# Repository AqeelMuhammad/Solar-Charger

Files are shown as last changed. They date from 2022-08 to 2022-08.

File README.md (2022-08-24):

# SOLAR BANK - Portable Solar Charger

<!-- PROJECT LOGO -->
<br />
<div align="center">
  <a href="https://github.com/AqeelMuhammad/Solar-Charger">
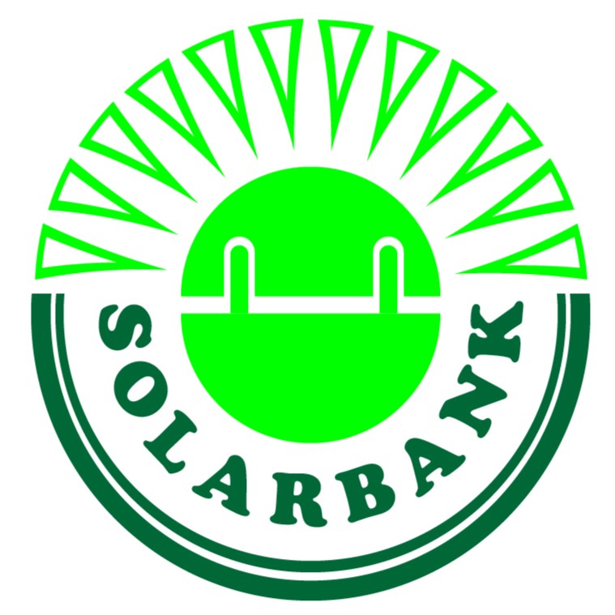
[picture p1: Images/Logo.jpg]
    
  </a>
  <h3 align="center">SOLAR BANK</h3>
</div>

# About The Project

<div align="center">
  <a href="https://github.com/AqeelMuhammad/Solar-Charger">
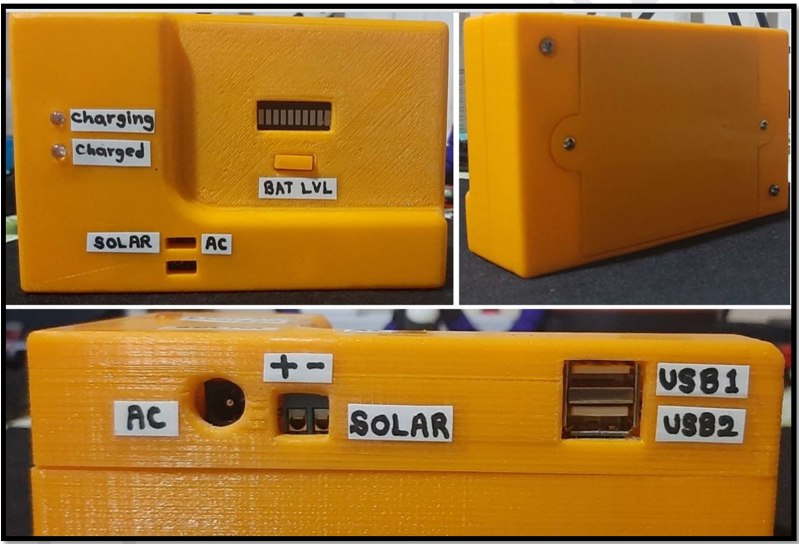
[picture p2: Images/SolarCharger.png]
    
  </a>
</div>

* This repository includes all the project files related to the development of a portable solar charger; Solar Bank. 
* The project was done by a team of 10 undergraduates at the Department of Electronic and Telecommunication Engineering, University of Moratuwa, Sri Lanka for UOM's EN3023 - Electronic Design Realization module.
* We Designed a portable mobile charger capable of powering small electronic devices which can be charged by solar cells or AC power. This device can be carried while hiking, traveling or can be installed in public places even at home.
* `Altium Designer` and `SolidWorks` were used to design the circuit designs and the enclosure designs.

# Printed Circuit Board (PCB)

|*3D Layout*|*Before Soldering*|*After Soldering*|
|:----:|:----:|:----:|
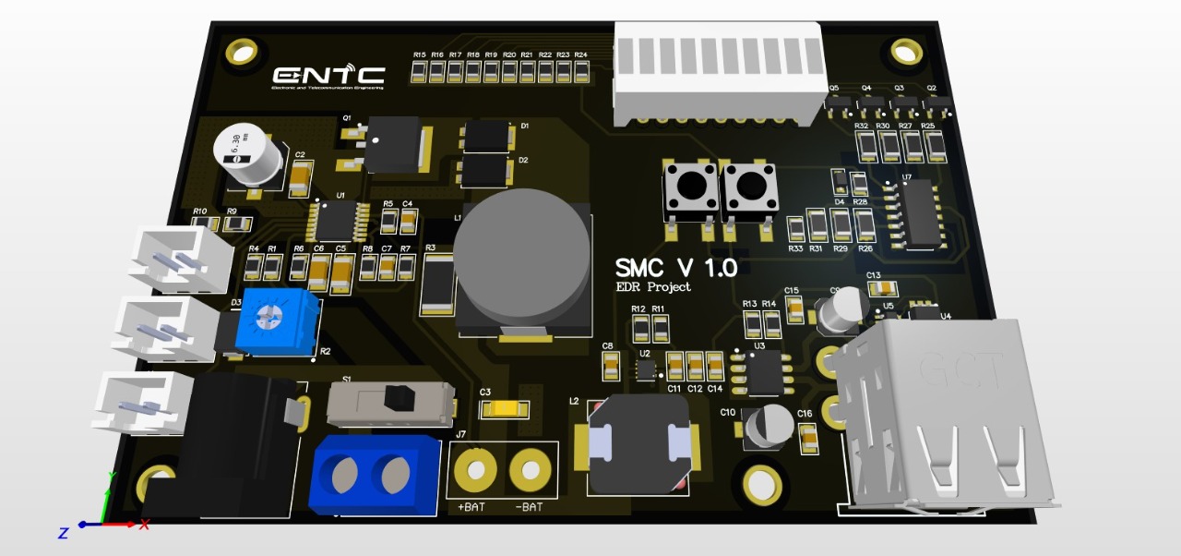
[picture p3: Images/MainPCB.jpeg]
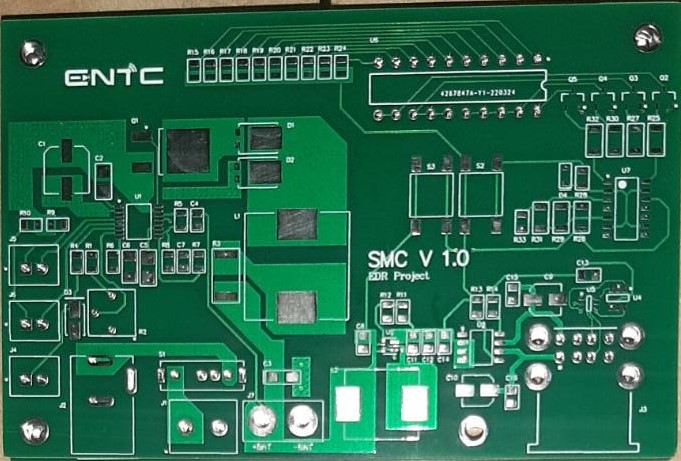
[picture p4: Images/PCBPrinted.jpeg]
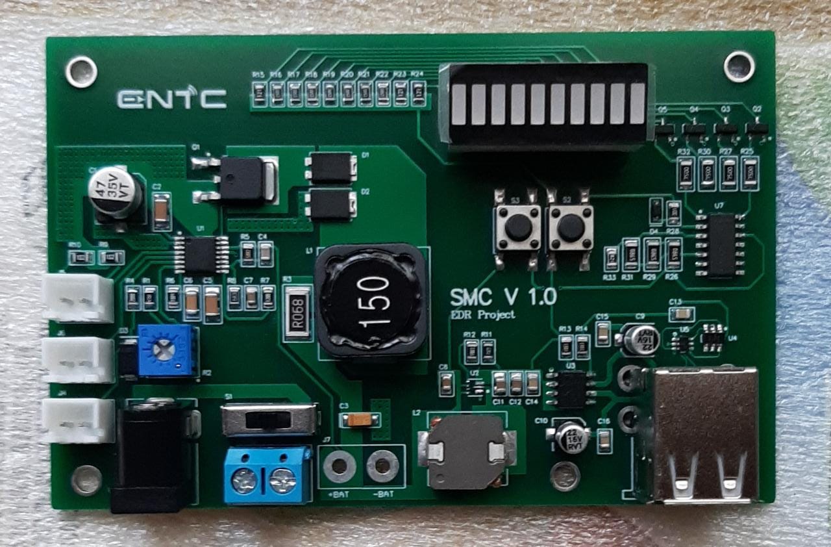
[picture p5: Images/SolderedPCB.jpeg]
|  |||

# Enclosure

|*SolidWork Design*|*Before Printing*|*After Printing*|
|:----:|:----:|:----:|
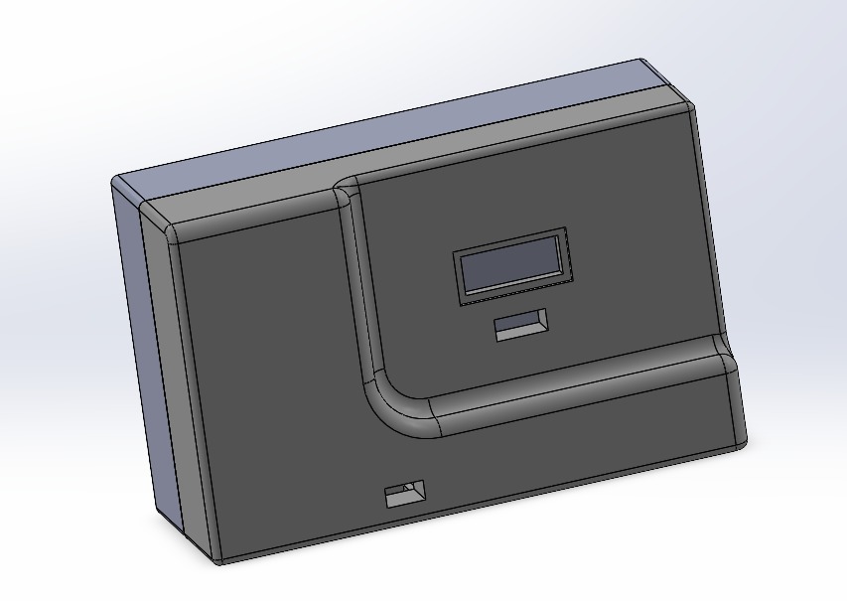
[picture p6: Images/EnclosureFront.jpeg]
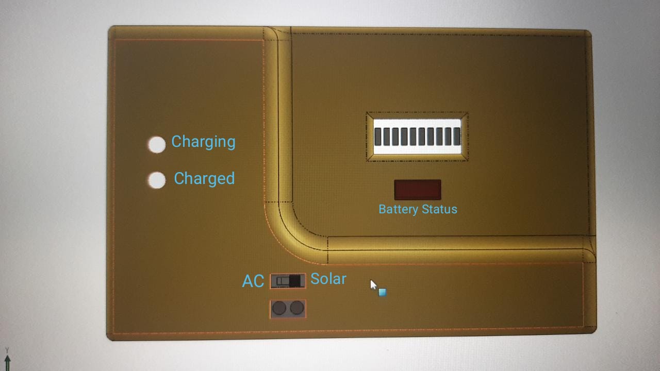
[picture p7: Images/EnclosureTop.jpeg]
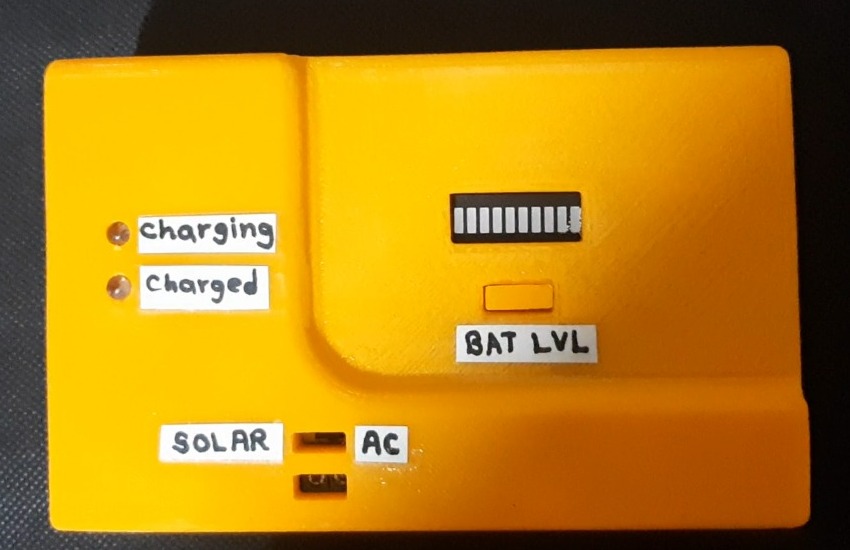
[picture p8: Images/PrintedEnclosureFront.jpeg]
|  |||

### Contributors

1. [Muhammad Aqeel](https://github.com/AqeelMuhammad)
1. [Charith Janaka](https://github.com/charithjanaka)
1. [Tharuka Nilupul](https://github.com/TharukaN17)
1. [Isuru Dilshan Wijethunga](https://github.com/IsuruWijethunga)
1. [Dilun Sandeepa](https://github.com/Diluwas)
1. [Navindu Rasanjana](https://github.com/NavinduRasanjana)
1. [Dulsara Gimhana](https://github.com/Dulsara20059)
1. [Aruna Lakpriya](https://github.com/aruna-lakpriya)
1. [Kaveesha Yalegama](https://github.com/Kaveesha-98)
1. [Janitha Vidunath](https://github.com/JanithaVidunath)

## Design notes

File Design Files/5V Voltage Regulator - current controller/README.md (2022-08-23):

# Step Down Voltage Regulator

* A voltage regulator and voltage step down circuit for the charger.

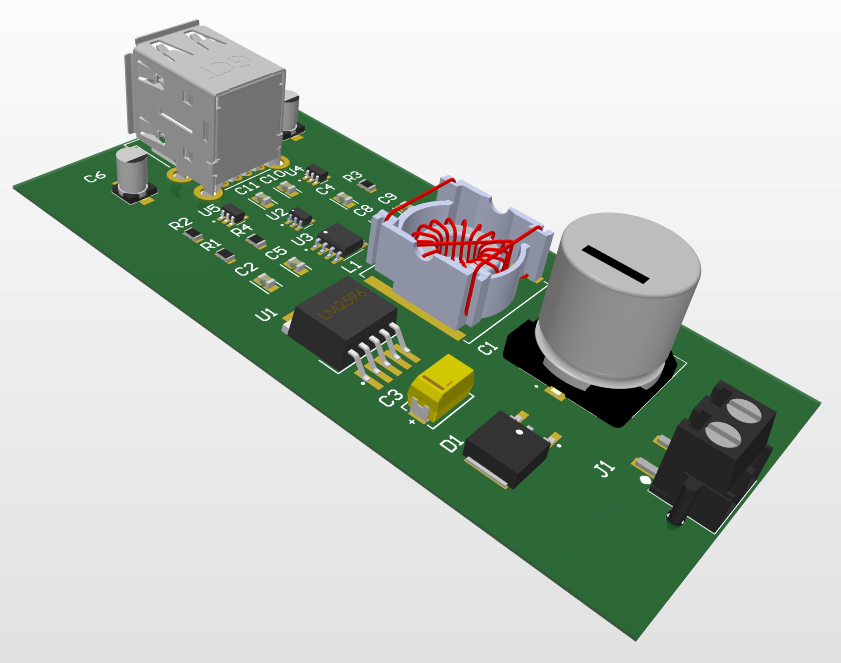
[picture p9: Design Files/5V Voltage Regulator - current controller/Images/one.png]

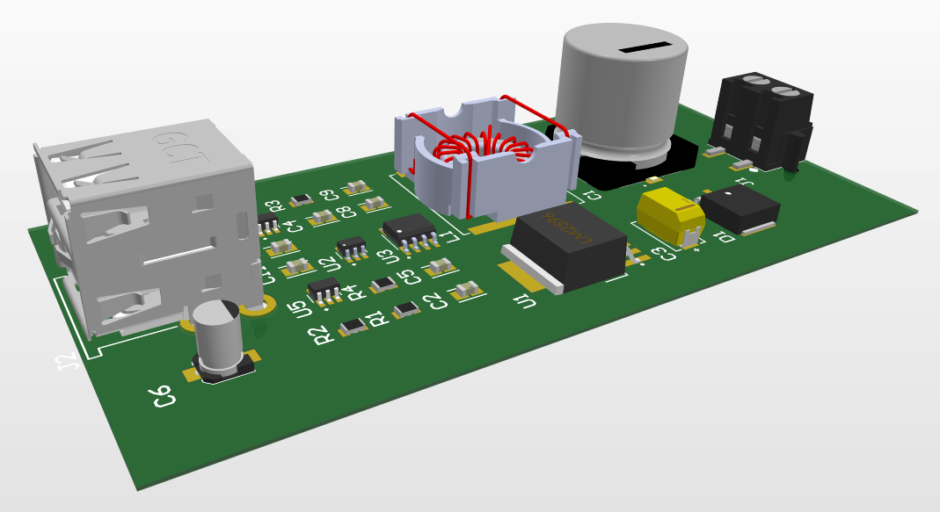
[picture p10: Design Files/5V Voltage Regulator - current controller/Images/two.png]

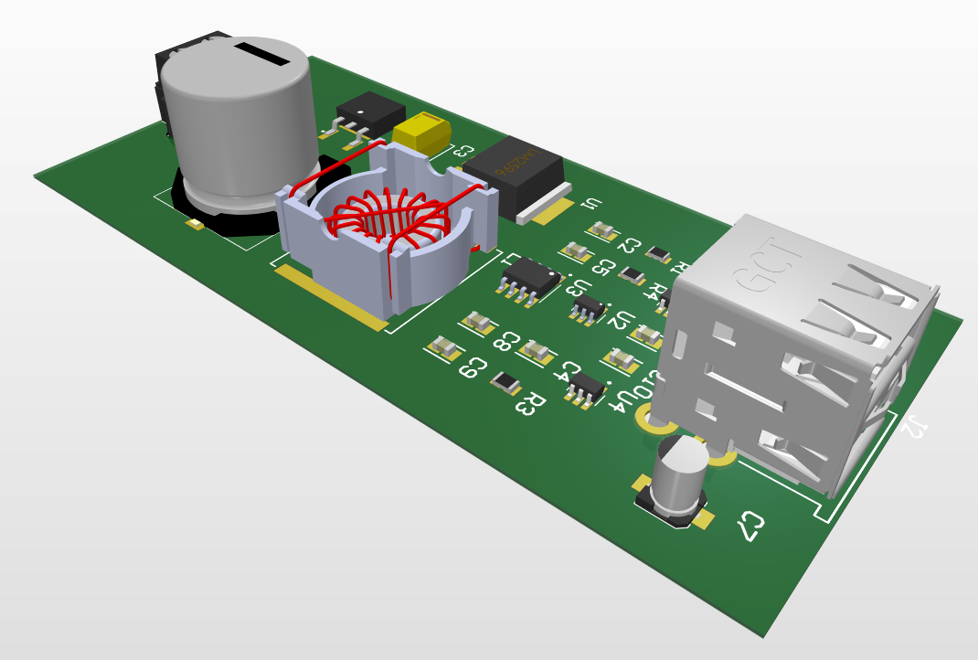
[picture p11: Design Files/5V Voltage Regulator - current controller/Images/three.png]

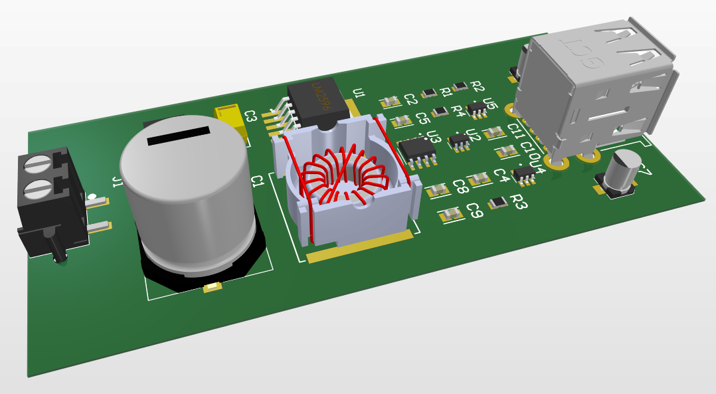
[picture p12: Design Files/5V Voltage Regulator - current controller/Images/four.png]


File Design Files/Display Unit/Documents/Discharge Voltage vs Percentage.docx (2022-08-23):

Nominal Voltage: 7.4V

Full charge: 8.4V

Capacity % | Voltage
100 | 8.4
95 | 8.3
90 | 8.22
85 | 8.16
80 | 8.05
75 | 7.97
70 | 7.91
65 | 7.83
60 | 7.75
55 | 7.71
50 | 7.67
45 | 7.63
40 | 7.59
35 | 7.57
30 | 7.53
25 | 7.49
20 | 7.45
15 | 7.41
10 | 7.37
5 | 7.22
0 | 6.55

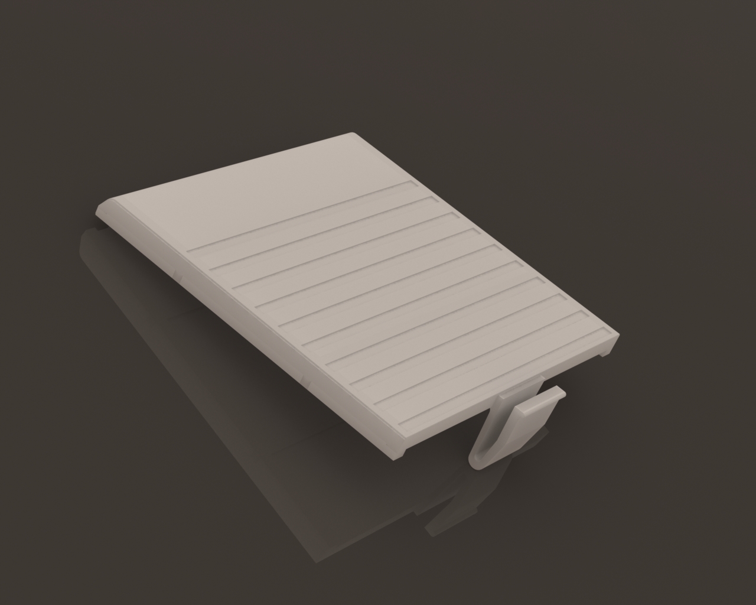
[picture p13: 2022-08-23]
Design Files/Enclosure/Battery case lid/Renderings/GameBoyBatteryCover4.JPG

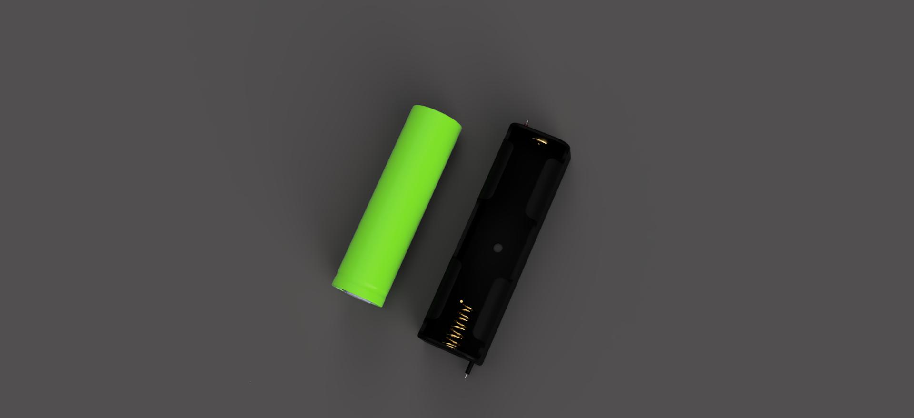
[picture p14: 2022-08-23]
Design Files/Enclosure/1xBatteryHolder/18650_battery_holder_2021-May-22_02-06-46PM-000_CustomizedView2157811146.jpg

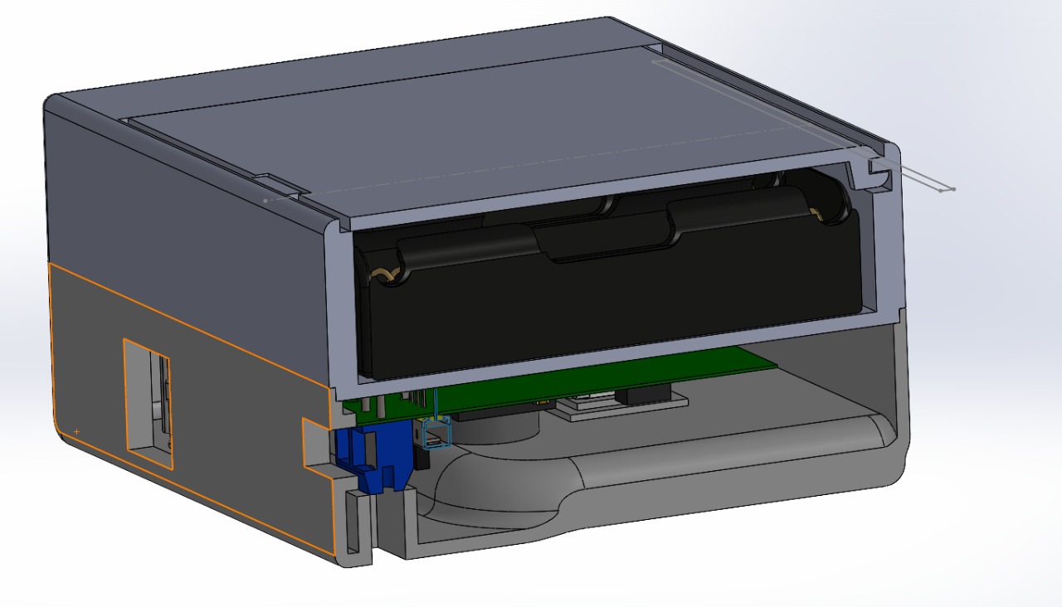
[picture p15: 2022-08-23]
Images/EnclosureSide.jpeg

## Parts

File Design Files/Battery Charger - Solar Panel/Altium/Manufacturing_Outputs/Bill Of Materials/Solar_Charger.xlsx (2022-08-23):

# | Designator | Description | Item | Manufacturer | Tolerance | Current | Voltage | Power | Footprint | Quantity | Manufacturer | Manufacturer Part Number | Manufacturer Lifecycle 1 | Supplier 1 | Supplier Part Number 1 | Supplier Unit Price (USD) | Supplier Subtotal (USD)
 | J1 | 2 Position Wire to Board Terminal Block Horizontal with Board 0.100" (2.54mm) Through Hole | 282834-2 | TE Connectivity AMP Connectors |  |  |  |  | 282834-2 | 1 | TE Connectivity | 282834-2 | Volume Production | Future Electronics | 6002975 | 0.79 | 0.79
 | J5 | 2 Position Wire to Board Terminal Block Horizontal with Board 0.100" (2.54mm) Through Hole | 282834-2 | TE Connectivity AMP Connectors |  |  |  |  | 282834-2 | 1 | TE Connectivity | 282834-2 | Volume Production | Future Electronics | 6002975 | 0.79 | 0.79
 | U1 | Linear Voltage Regulator IC Positive Fixed 1 Output 100mA | AS78L05RTR-G1 | Diodes Incorporated |  |  |  |  | SOT150P288X160-3N (SOT89) | 1 | Diodes | AS78L05RTR-G1 | Volume Production | Arrow Electronics | AS78L05RTR-G1 | 0.4182 | 0.4182
 | L1 | 22 µH Unshielded Wirewound Inductor 3.5 A 47mOhm Max Nonstandard | ASPI-1306T-220M-T | Abracon LLC |  |  |  |  | INDC185152X711N | 1 | Abracon | ASPI-1306T-220M-T | Volume Production | Mouser | 815-ASPI-1306T-220M | 1.81 | 1.81
 | J2 | Connector Header Through Hole 2 position 0.098" (2.50mm) | B2B-XH-A(LF)(SN) | JST Sales America Inc. |  |  |  |  | B2B-XH-A(LF)(SN) | 1 | JST | B2B-XH-A(LF)(SN) | Volume Production | Future Electronics | 1638840 | 0.128 | 0.128
 | J3, J4 | Connector Header Through Hole 2 position 0.098" (2.50mm) | B2B-XH-A(LF)(SN) | JST Sales America Inc. |  |  |  |  | B2B-XH-A(LF)(SN) | 2 | JST | B2B-XH-A(LF)(SN) | Volume Production | RSComponents | 8201554 | 0.273 | 1.37
 | C4 | 0.015 µF ±1% 16V Ceramic Capacitor U2J | C0805C153F4JAC7800 | KEMET |  |  | 16V |  | CAPC200125X088N (0805) | 1 | KEMET | C0805C153F4JAC7800 | Unknown | Digi-Key | C0805C153F4JAC7800-ND | 0.38848 | 0.38848
 | C8 | 22 µF ±20% 35V Ceramic Capacitor X5R | C3216X5R1V226M160AC | TDK Corporation |  |  | 35V |  | CAPC320160X180N_A (1206) | 1 | TDK | C3216X5R1V226M160AC | Volume Production | Mouser | 810-C3216X5R1V226M | 1.05 | 1.05
 | C2 | 0.1 µF ±10% 50V Ceramic Capacitor X7R | CL21B104KBCNNNC | Samsung Electro-Mechanics |  |  | 50V |  | CAPC200125X094N (0805) | 1 | Samsung | CL21B104KBCNNNC | Volume Production | Newark | 82AC9428 | 0.005 | 0.005
 | C1 | CAP CER 0.33UF 50V X7R 0805 | CL21B334KBFNNNE | Samsung Electro-Mechanics |  |  | 50V |  | CAPC200125X135N (0805) | 1 | Samsung | CL21B334KBFNNNE | Volume Production | Arrow Electronics | CL21B334KBFNNNE | 0.0825 | 0.0825
 | U2 | MOSFET P-CH 30V 3.8A | DMP3085LSS-13 | Diodes Incorporated |  |  |  |  | SOIC127P600X175-8N | 1 | Diodes | DMP3085LSS-13 | Volume Production | Digi-Key | DMP3085LSS-13DICT-ND | 0.46 | 0.46
 | R3 | 510 kOhms ±5% 0.125W, 1/8W Chip Resistor | ERJ-6GEYJ514V | Panasonic Electronic Components | 5% |  |  |  | RESC200125X070N (0805) | 1 | Panasonic | ERJ-6GEYJ514V | Volume Production | Newark | 53W4964 | 0.002 | 0.002
 | C6, C7 | 0.56 µF ±10% 16V Ceramic Capacitor X7R | GRM219R71C564KA01D | Murata Electronics |  |  | 16V |  | CAPC200125X095N (0805) | 2 | Murata | GRM219R71C564KA01D | Volume Production | Arrow Electronics | GRM219R71C564KA01D | 0.3651 | 0.7302
 | U3 | IC BATT CHG LI-ION 2CELL | LTC4006EGN-6#PBF | Analog Devices Inc. |  |  |  |  | SOP064P600X175-16N | 1 | Analog Devices / Linear Technology | LTC4006EGN-6#PBF | Volume Production | Digi-Key | LTC4006EGN-6#PBF-ND | 9.66 | 9.66
 | D1 | Diode Schottky 30 V 1A Surface Mount | MBR130T1G | onsemi |  |  |  |  | DIOC269160X135N (SOD 123) | 1 | ON Semiconductor | MBR130T1G | Volume Production | Newark | 31Y2493 | 0.096 | 0.096
 | R1 | 330 Ohms ±5% 0.25W, 1/4W Chip Resistor | RK73B2ATTD331J | KOA Speer Electronics, Inc. | 5% |  |  |  | RESC200125X060N (0805) | 1 | KOA Speer | RK73B2ATTD331J | Volume Production | Digi-Key | 2019-RK73B2ATTD331JCT-ND | 0.1 | 0.1
 | R5 | 24 kOhms ±1% 0.25W, 1/4W Chip Resistor | RK73H2ATTD2402F | KOA Speer Electronics, Inc. | 1% |  |  |  | RESC200125X065N_A (0805) | 1 | KOA Speer | RK73H2ATTD2402F | Volume Production | Digi-Key | 2019-RK73H2ATTD2402FCT-ND | 0.1 | 0.1
 | R9 | 309 kOhms ±1% 0.25W, 1/4W Chip Resistor | RK73H2ATTD3093F | KOA Speer Electronics, Inc. | 1% |  |  |  | RESC200125X065N_A (0805) | 1 | KOA Speer | RK73H2ATTD3093F | Volume Production | Mouser | 660-RK73H2ATTD3093F | 0.1 | 0.1
 | R7 | 6.04 kOhms ±1% 0.25W, 1/4W Chip Resistor | RK73H2ATTD6041F | KOA Speer Electronics, Inc. | 1% |  |  |  | RESC200125X065N_A (0805) | 1 | KOA Speer | RK73H2ATTD6041F | Volume Production | Arrow Electronics | RK73H2ATTD6041F | 0.0862 | 0.0862
 | R8 | 95.3 kOhms ±1% 0.25W, 1/4W Chip Resistor | RK73H2ATTD9532F | KOA Speer Electronics, Inc. | 1% |  |  |  | RESC200125X065N_A (0805) | 1 | KOA Speer | RK73H2ATTD9532F | Volume Production | Digi-Key | 2019-RK73H2ATTD9532FCT-ND | 0.1 | 0.1
 | R2 | 5 kOhms ±0.1% 0.1W, 1/10W Chip Resistor | RT0603BRE075KL | YAGEO | 0.1% |  |  |  | RESC160075X055N (0603) | 1 | Yageo | RT0603BRE075KL | Unknown | Digi-Key | 13-RT0603BRE075KLCT-ND | 0.4 | 0.4
 | U4 | Mosfet Array N and P-Channel 20V 12A, 9A 3.5W | SI7540ADP-T1-GE3 | Vishay Siliconix |  |  |  |  | SON127P620X112-8N | 1 | Vishay | SI7540ADP-T1-GE3 | Unknown | Digi-Key | SI7540ADP-T1-GE3CT-ND | 1.84 | 1.84
 | C5 | 33 µF Molded Tantalum Capacitors 16 V 2312 (6032 Metric) 200mOhm @ 100kHz | T495C336K016ATE200 | KEMET |  |  | 16V |  | CAPC730430X060N (2312) | 1 | KEMET | T495C336K016ATE200 | Volume Production | Mouser | 80-T495C336K16ATE200 | 2.2 | 2.2
 | C3 | 10 µF Molded Tantalum Capacitors 35 V | T495D106K035AHE125 | KEMET |  |  | 35V |  | CAPC730430X031N (2917) | 1 | KEMET | T495D106K035AHE125 | Volume Production | Newark | 60M2443 | 1.49 | 1.49
 | R4, R6 | 33 mOhms ±1% 0.5W, 1/2W Chip Resistor | UR73VD2ATTD33L0F | KOA Speer Electronics, Inc. | 1% |  |  |  | RESC200125X070N (0805) | 2 | KOA Speer | UR73VD2ATTD33L0F | Unknown | Arrow Electronics | UR73VD2ATTD33L0F | 0.1196 | 0.2392
 |  |  |  |  |  |  |  |  |  |  |  |  |  |  |  | 22.85408 | 24.43578

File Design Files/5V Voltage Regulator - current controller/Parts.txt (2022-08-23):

C1,C2,C3,C4		Yageo					CC0805KRX7R9BB104
C5,C6			ROQANG					RVT1C220M0405
J2			Jing Extension of the Electronic Co. 	907-111A1012D10200
R1,R2			Viking Tech				ARG05FTC1003
U1			Texas Instruments			TPS2066DR
U2			Texas Instruments			TPS2513DBVRs
U3			Texas Instruments 			TPD4E1U06DCKR

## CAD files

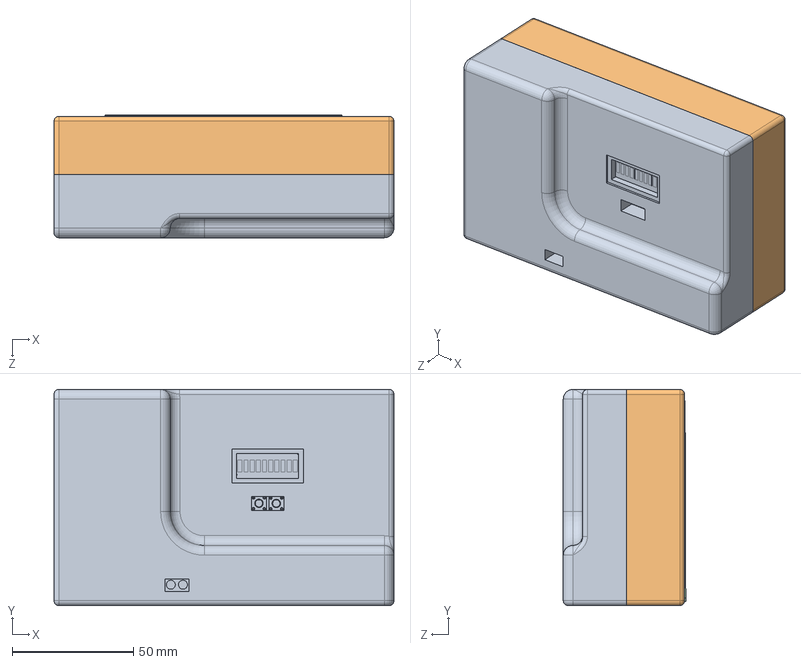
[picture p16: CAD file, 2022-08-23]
Design Files/Enclosure/Assem1.SLDASM
140.0 x 89.0 x 50.5 mm
front part newest
Rear part
18650 battery holder x 4
lid

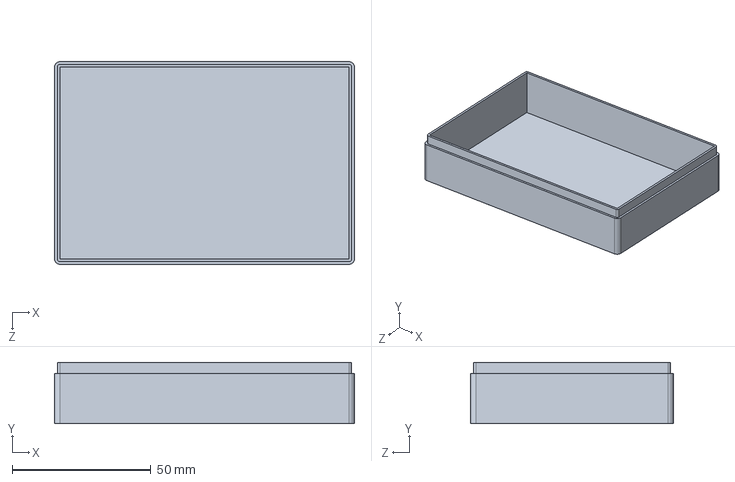
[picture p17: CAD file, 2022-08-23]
Design Files/Enclosure/back1.SLDPRT
108.0 x 22.0 x 73.0 mm

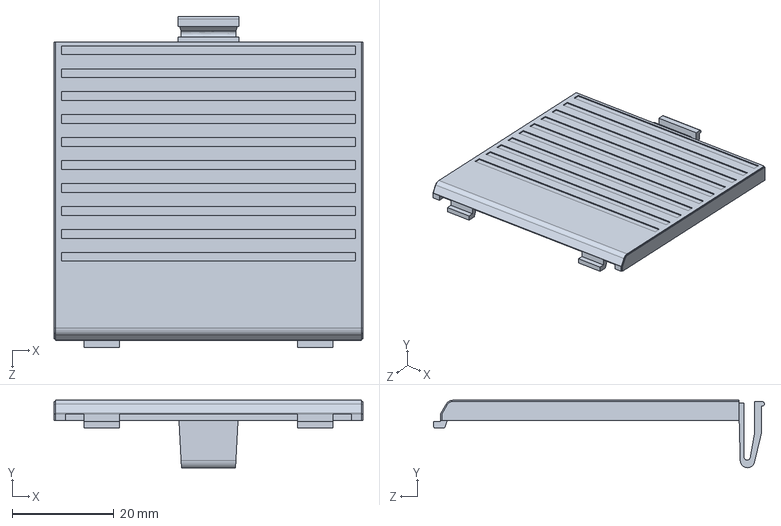
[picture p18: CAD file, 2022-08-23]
Design Files/Enclosure/Battery case lid/GameBoyBatteryCover.SLDPRT
60.6 x 13.2 x 64.9 mm

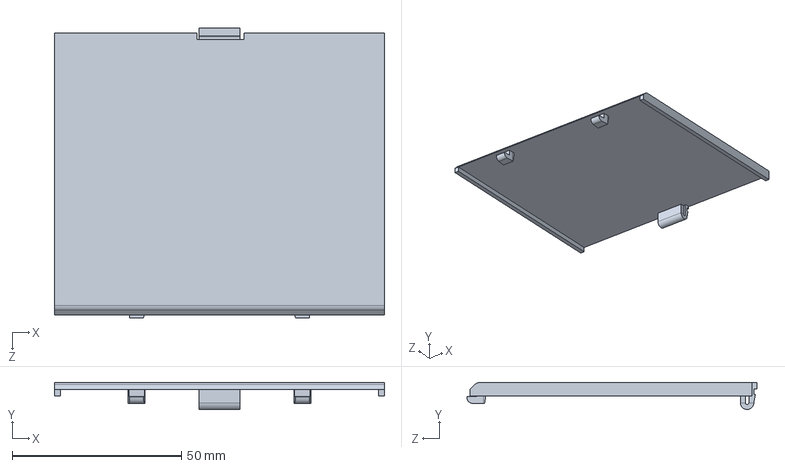
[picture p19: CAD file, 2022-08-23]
Design Files/Enclosure/lid.SLDPRT
97.6 x 7.99 x 85.9 mm

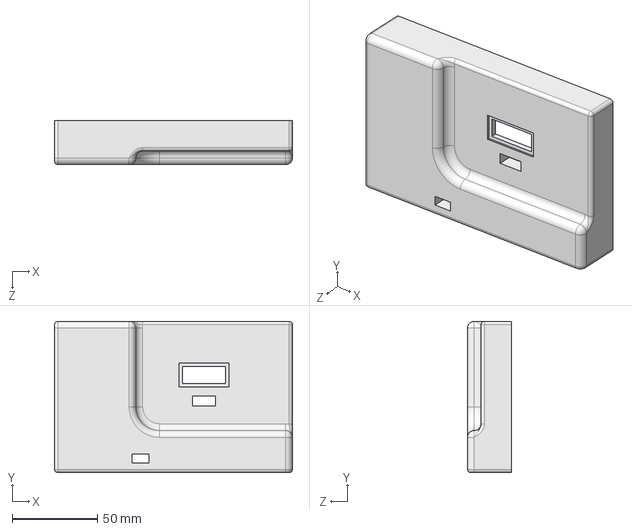
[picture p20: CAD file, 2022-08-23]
Design Files/Enclosure/frontSTEP.STEP
140.0 x 89.0 x 26.0 mm

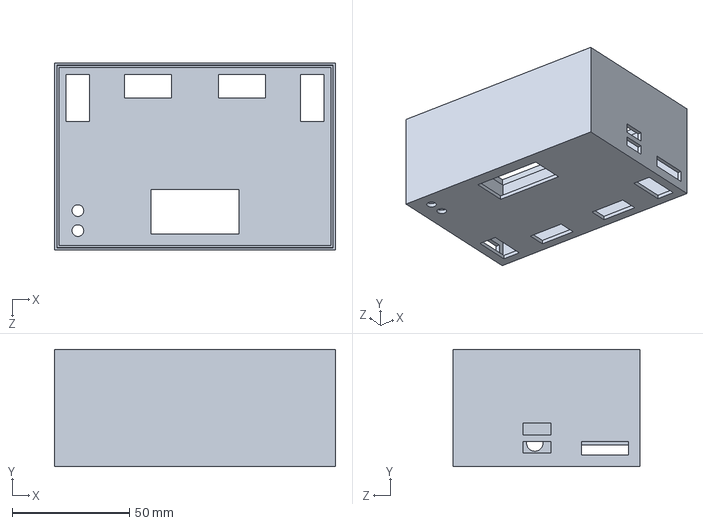
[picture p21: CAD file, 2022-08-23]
Design Files/Enclosure/Part1.SLDPRT
120.0 x 50.0 x 80.0 mm

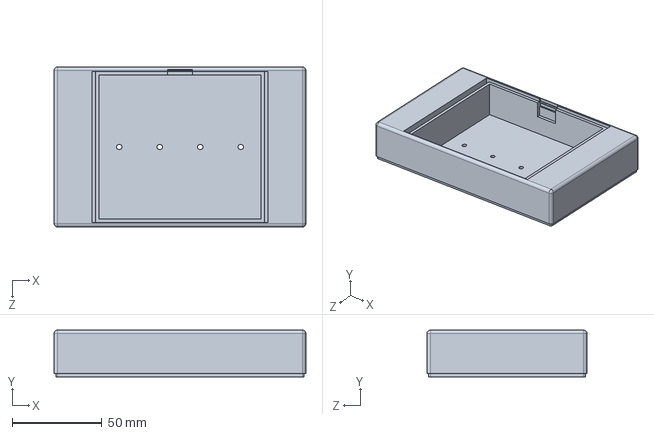
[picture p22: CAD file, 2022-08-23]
Design Files/Enclosure/Rear part.SLDPRT
140.0 x 26.0 x 89.0 mm

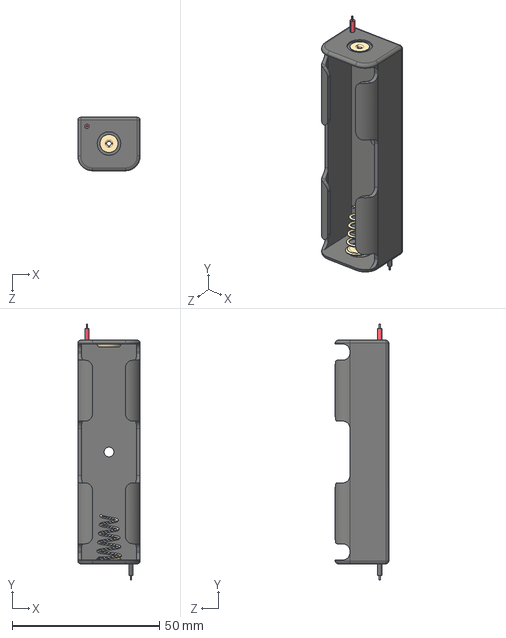
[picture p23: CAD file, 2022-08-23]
Design Files/Enclosure/1xBatteryHolder/18650 battery holder.STEP
21.2 x 87.0 x 18.2 mm

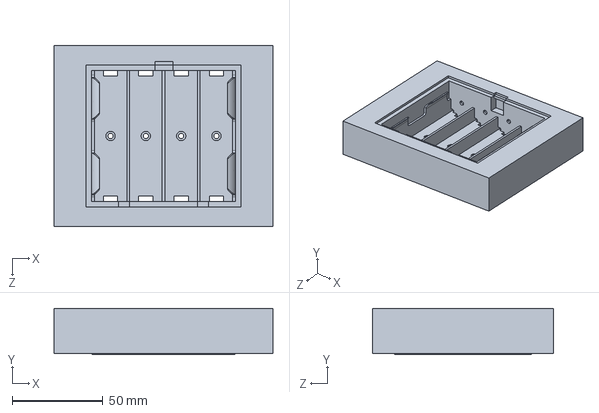
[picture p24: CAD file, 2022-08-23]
Design Files/Enclosure/18650 Battery Holder 4x-18650 Battery Holder 4x.STEP1.SLDPRT
121.0 x 25.5 x 100.0 mm

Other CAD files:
Design Files/Enclosure/front part step.STEP
Design Files/Enclosure/frontSTEP.step.SLDPRT
Design Files/Enclosure/1xBatteryHolder/18650 battery holder.SLDPRT
Design Files/Enclosure/1xBatteryHolder/18650 battery holder.f3d
Design Files/Enclosure/1xBatteryHolder/18650 battery holder.iges
Design Files/Enclosure/1xBatteryHolder/18650 battery holder.stl
Design Files/Enclosure/Battery case lid/GameBoyBatteryCover.IGS

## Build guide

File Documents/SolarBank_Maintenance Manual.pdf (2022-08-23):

# Maintenance Manual

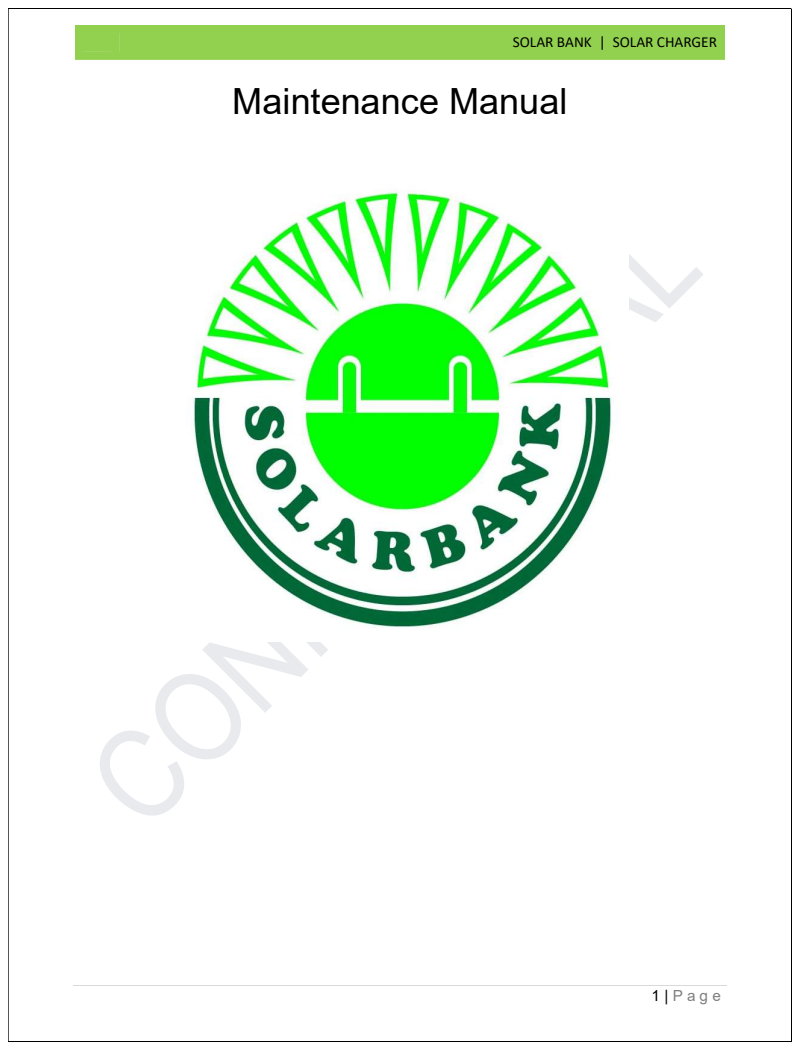
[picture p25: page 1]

SOLAR BANK | SOLAR CHARGER

# Table of Contents

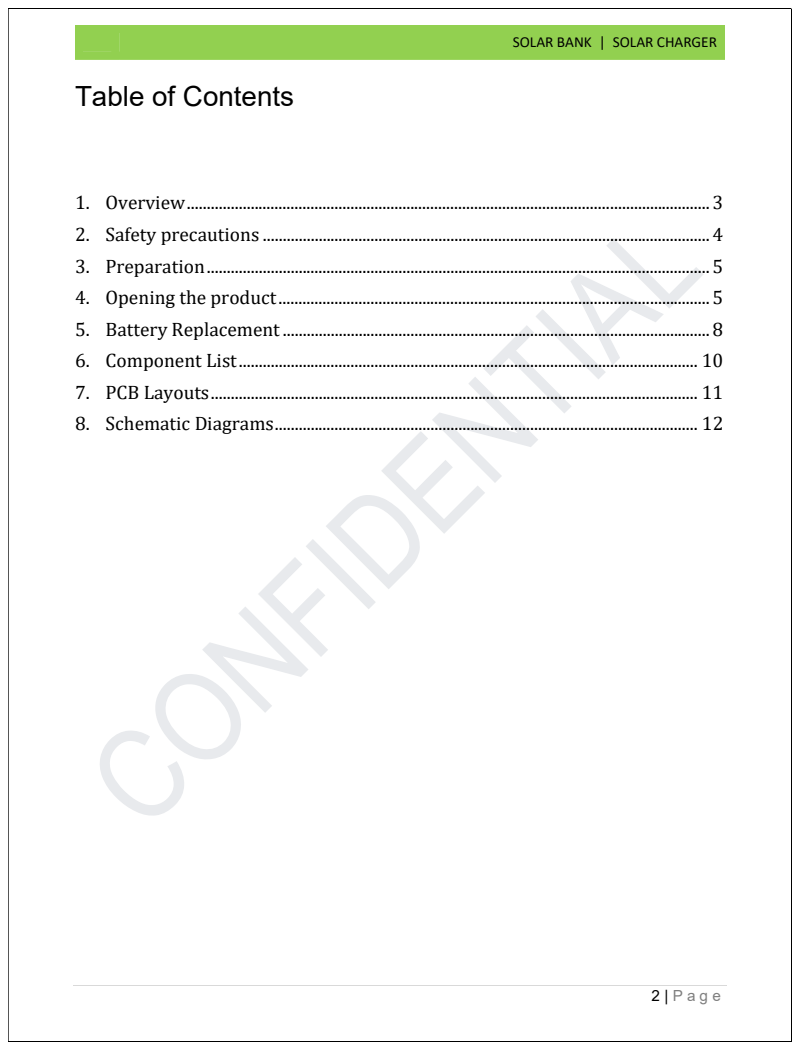
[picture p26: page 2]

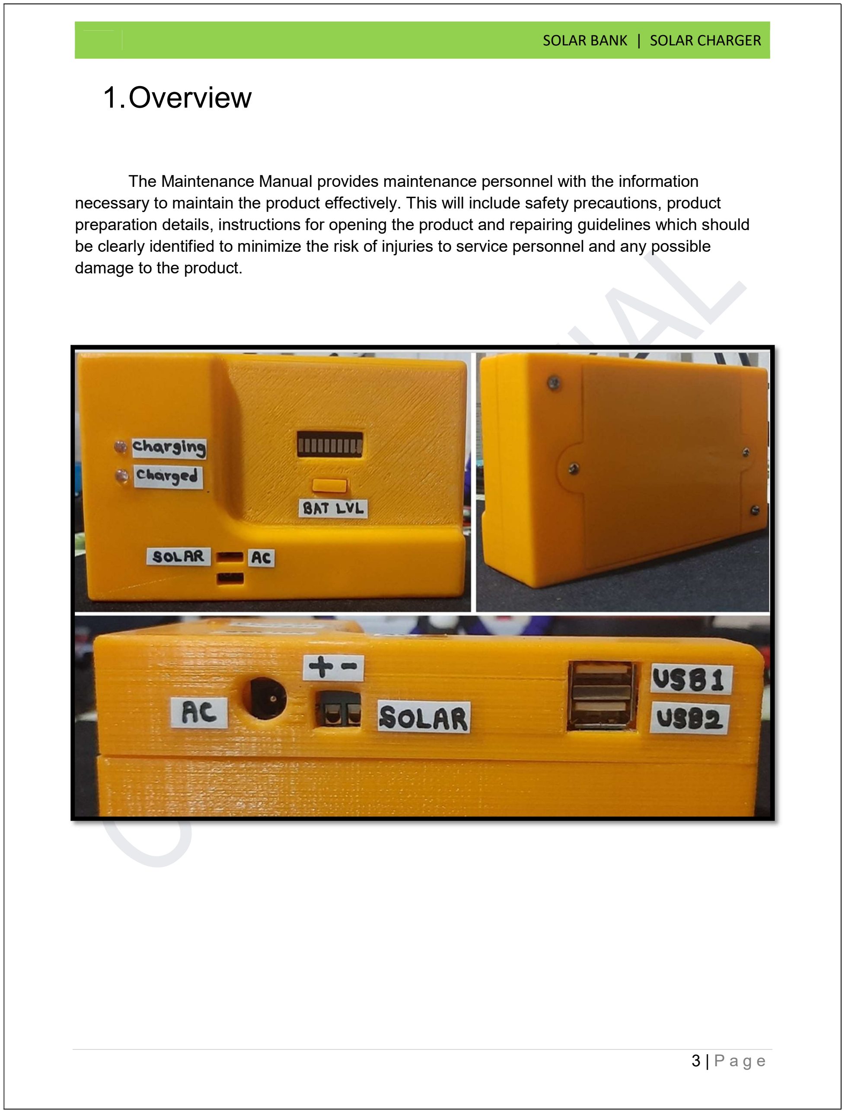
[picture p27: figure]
1. Overview; damage to the product.

The Maintenance Manual provides maintenance personnel with the information necessary to maintain the product effectively. This will include safety precautions, product preparation details, instructions for opening the product and repairing guidelines which should be clearly identified to minimize the risk of injuries to service personnel and any possible

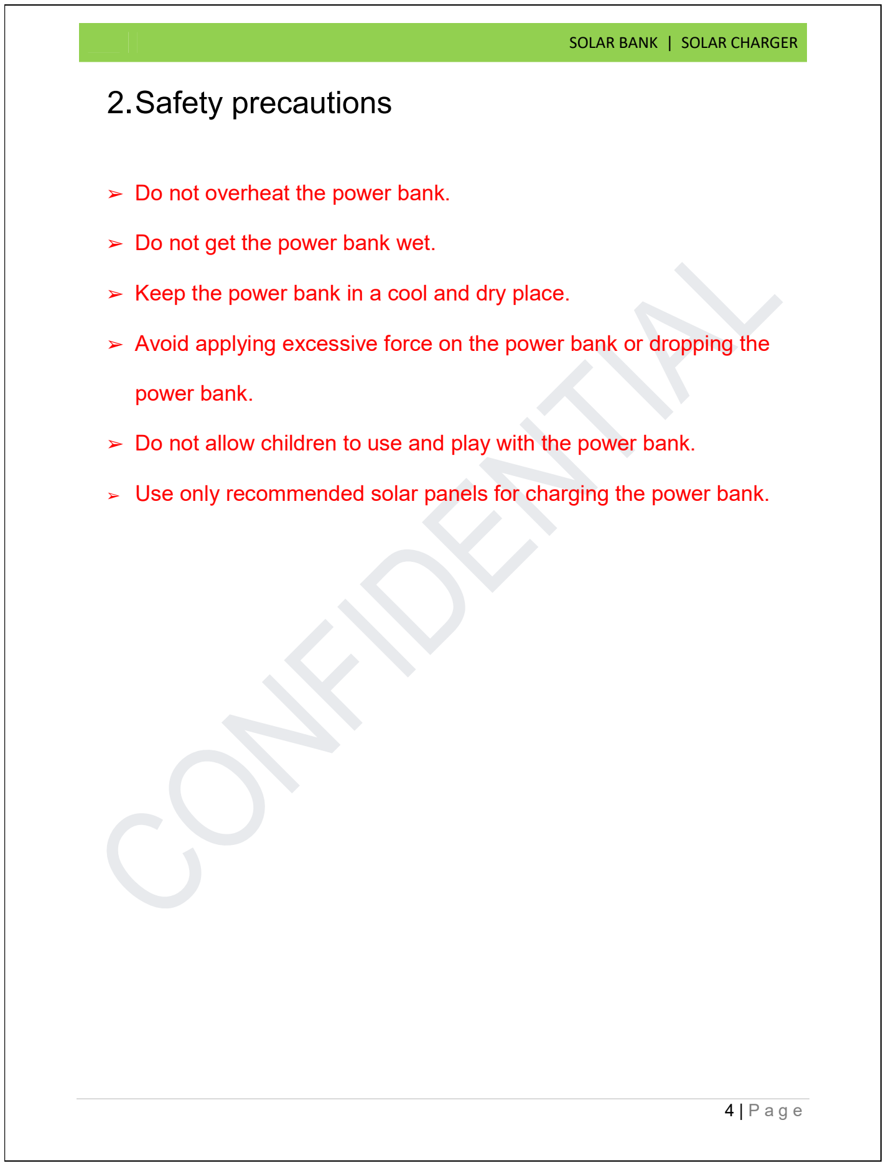
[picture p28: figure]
2. Safety precautions; ➢ Do not overheat the power bank.; ➢ Do not get the power bank wet.; power bank.

- Keep the power bank in a cool and dry place.

### - Avoid applying excessive force on the power bank or dropping the

- Do not allow children to use and play with the power bank.
- Use only recommended solar panels for charging the power bank.

5 | P a g e

# 3. Preparation

Follow these simple tests before disassembling the device.

- Check whether the AC power adapter has proper voltage output and the continuity of the

power cable.

- Check whether the solar panel has proper voltage output and the continuity of the cable.
- Check whether the polarity of the solar panel cables are connected correctly.
- Observe whether the switches and sockets of the device are operating properly.
- Check the battery level by looking at the indicator.

# 4. Opening the product

Important!
You should remove batteries before opening the product. Steps of removing batteries have been listed under section 05.
Step 01 - Disconnect the solar panel cables, the AC adapter, and the USB cables from ports.

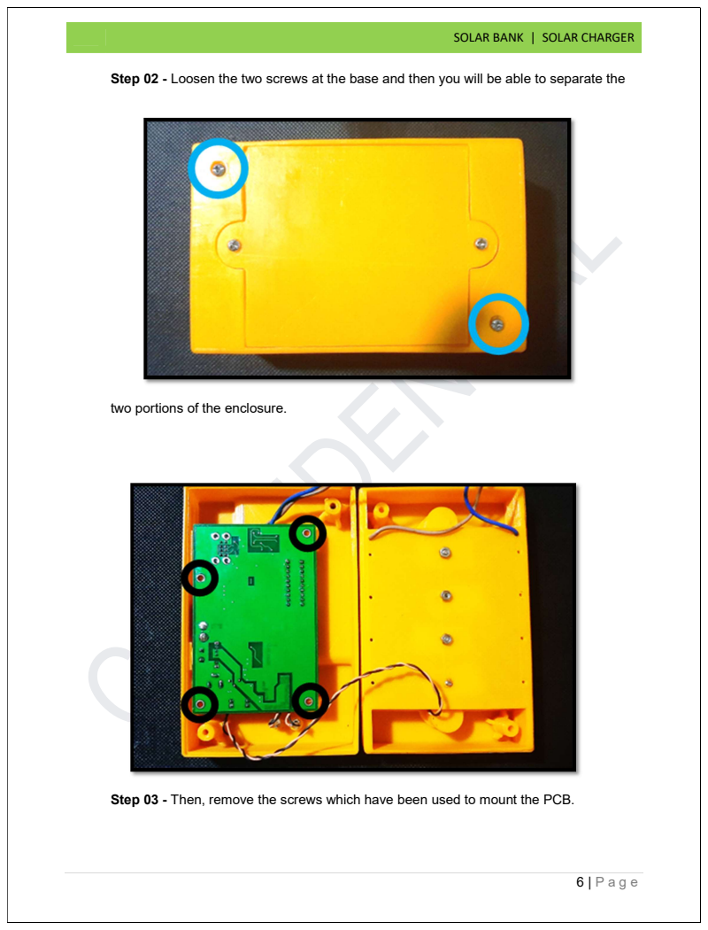
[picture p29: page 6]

Step 02 - Loosen the two screws at the base and then you will be able to separate the

two portions of the enclosure.

Step 03 - Then, remove the screws which have been used to mount the PCB.

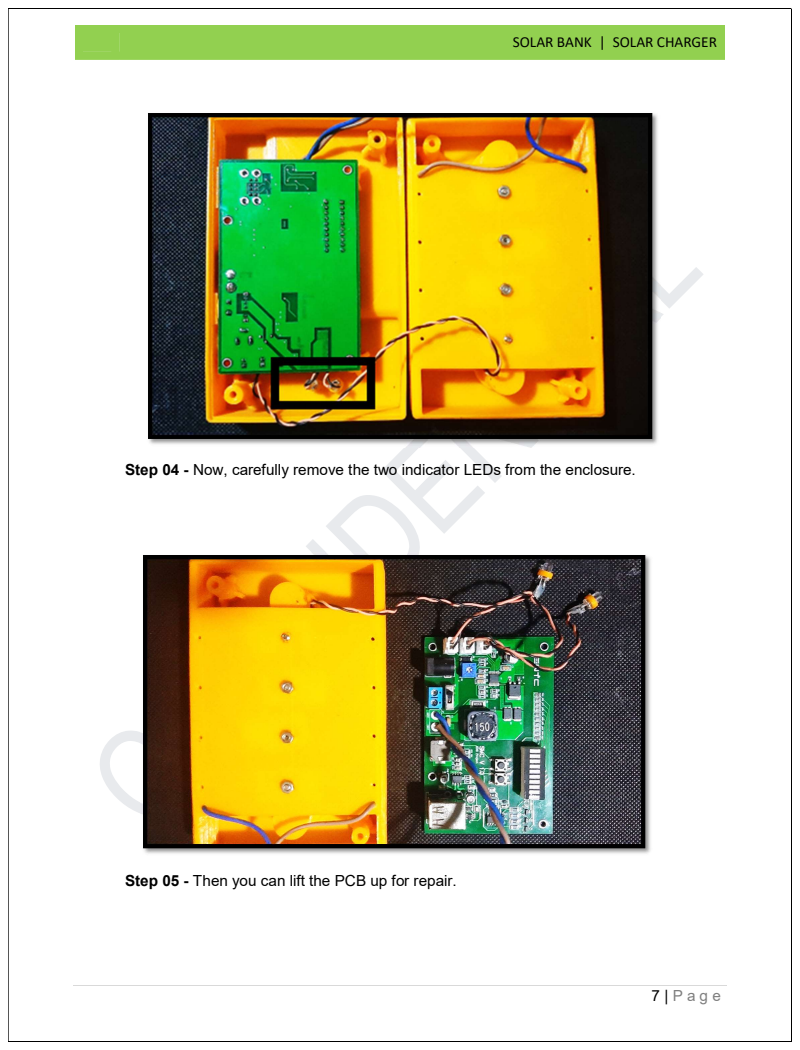
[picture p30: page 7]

Step 04 - Now, carefully remove the two indicator LEDs from the enclosure.

Step 05 - Then you can lift the PCB up for repair.

# 5. Battery Replacement

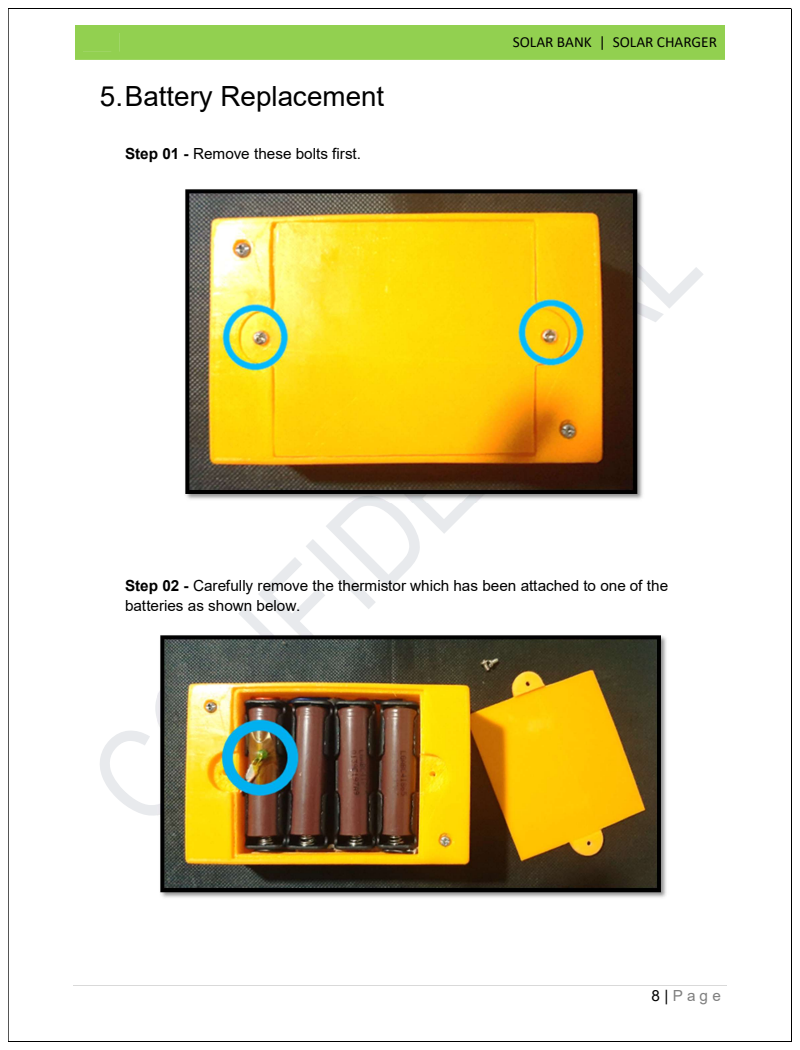
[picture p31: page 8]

Step 01 - Remove these bolts first.

Step 02 - Carefully remove the thermistor which has been attached to one of the
batteries as shown below.

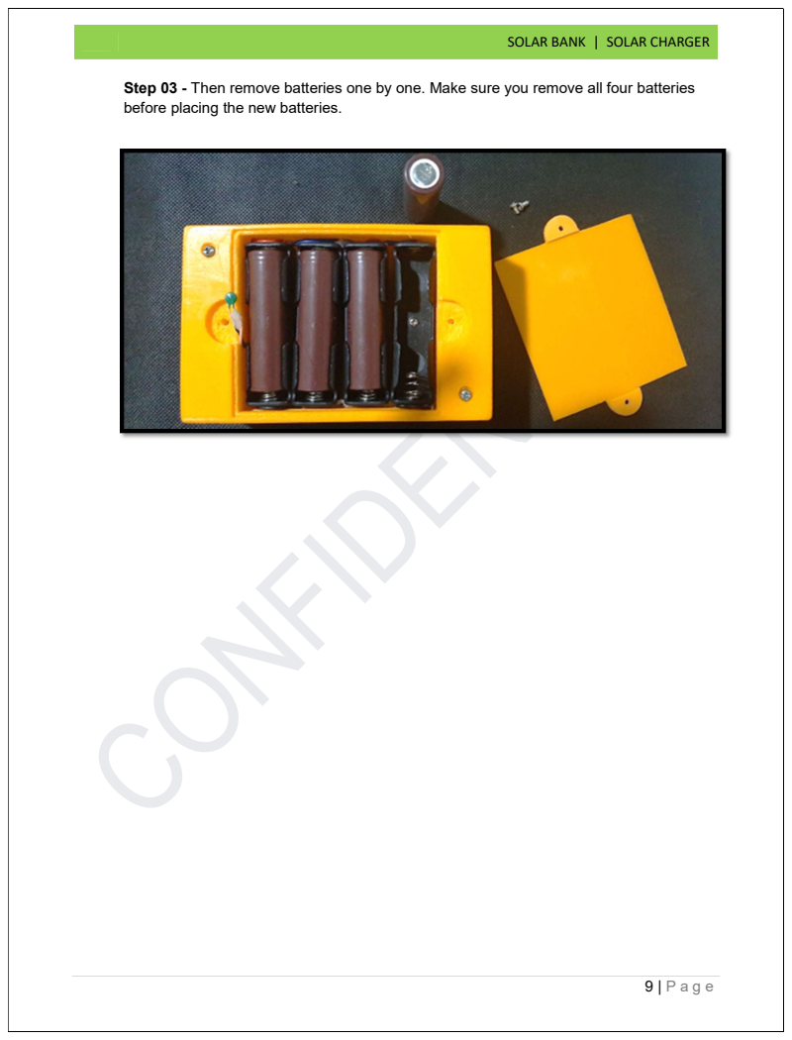
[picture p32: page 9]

Step 03 - Then remove batteries one by one. Make sure you remove all four batteries
before placing the new batteries.

# 6. Component List

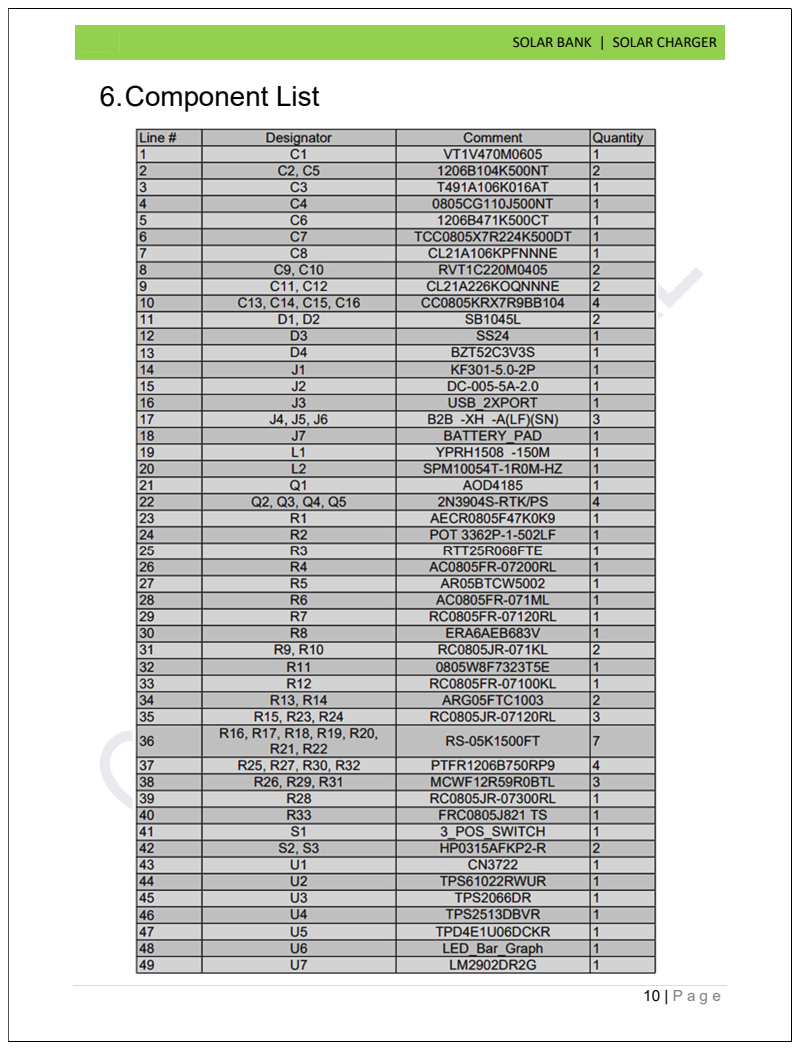
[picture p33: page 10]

# 7. PCB Layouts

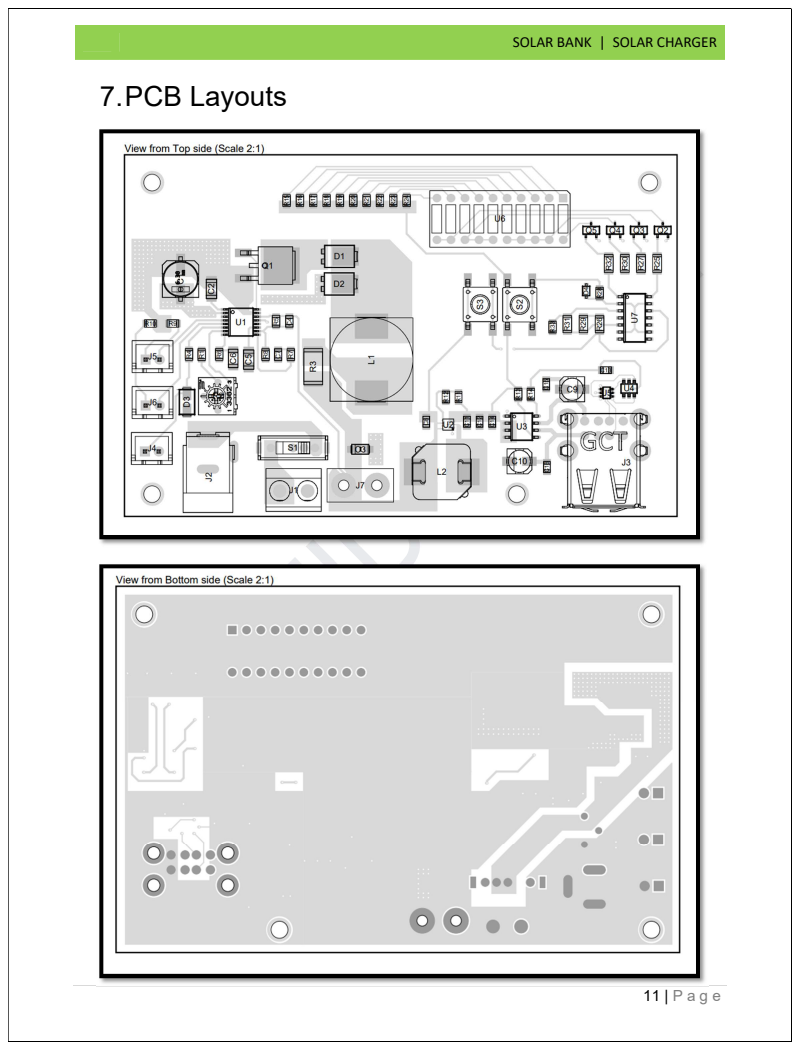
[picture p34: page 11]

# 8. Schematic Diagrams

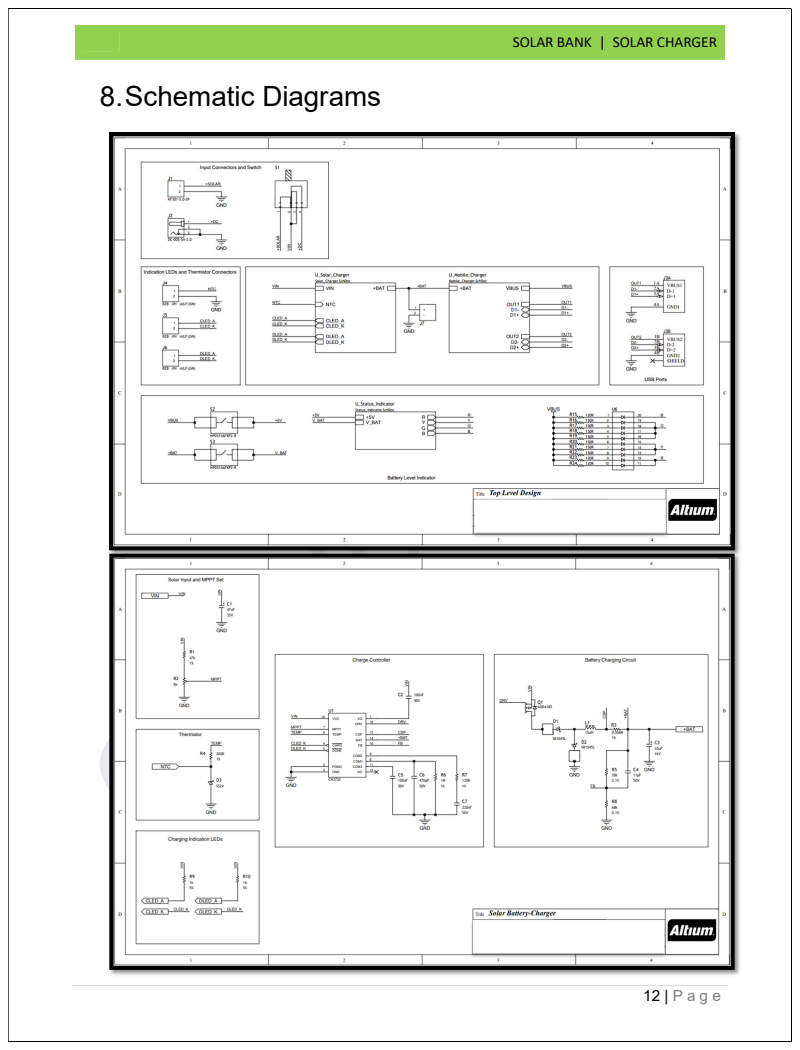
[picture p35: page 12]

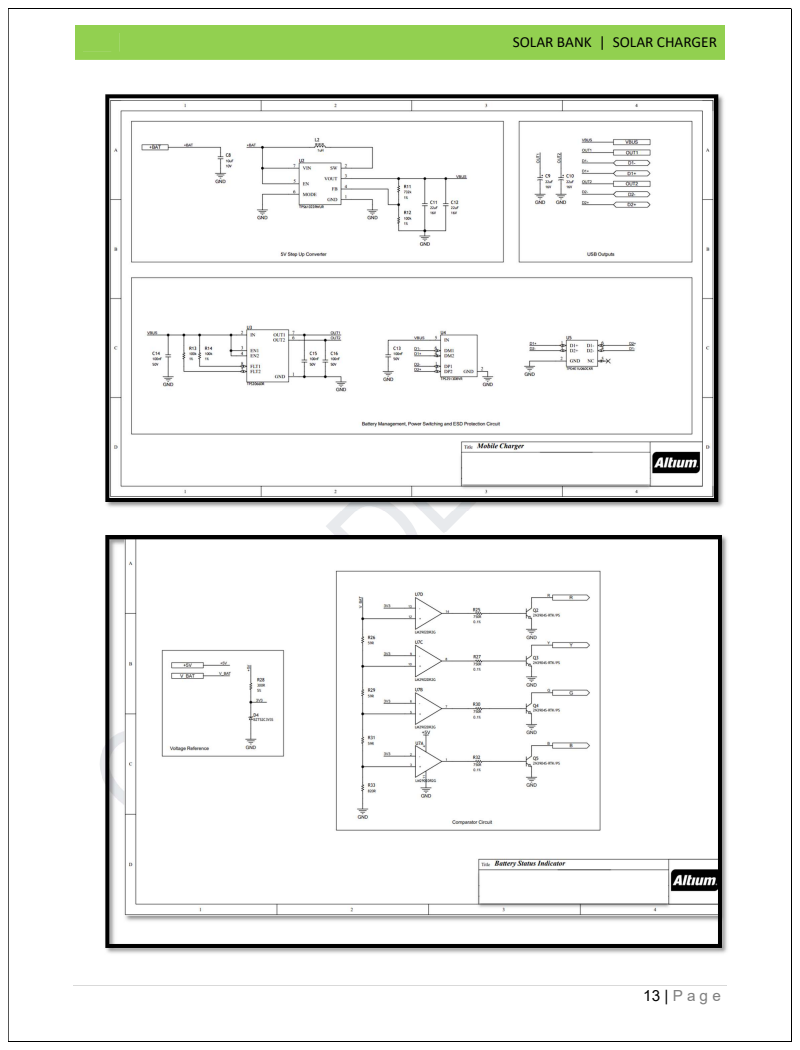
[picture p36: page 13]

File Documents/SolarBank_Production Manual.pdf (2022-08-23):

## SOLAR BANK | SOLAR CHARGER

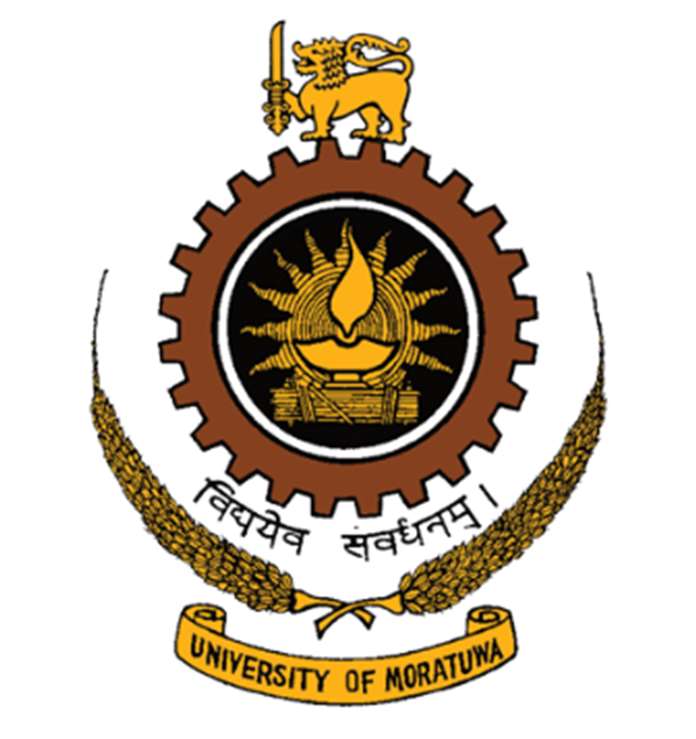
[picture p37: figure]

# Department of Electronics & Telecommunication Engineering University of Moratuwa EN3023 – Electronic Design Realization

# SolarBank

## PRODUCTION DOCUMENT

1. T.M. AQEEL | 180039C
2. M.M.C.J. BANDARA | 180065C
3. A.M.J.V. COSTA | 180101K
4. D.N.R. DISSANAYAKE | 180153U
5. H.A.D.G. HETTIARACHCHI | 180236D
6. U.W.R.AL. KARUNATHILAKA | 180316A
7. R.T.N. RATHNAYAKE | 180538F
8. T.A.D.S THENNAKOON | 180639P
9. U.I.D WIJETHUNGA | 180715V
10. M.M.K.A.B. YALEGAMA | 180720G

THIS REPORT IS SUBMITTED IN PARTIAL FULFILLMENT OF THE REQUIREMENTS FOR THE MODULE EN3023 – ELECTRONIC DESIGN REALIZATION

### 05TH OF JUNE 2022

# 1. GENERAL INFORMATION

## 1.1. OVERVIEW

SolarBank is a portable mobile charger that can be used to charge mobile phones, power banks, MP3 players etc. This charger can be charged using two ways. The main method of powering the charger is using the solar cells. Alternatively, AC voltage can be used to charge the product in the absence of sunlight. The product can be installed in public places such as railway stations, bus stands, markets etc. and can be carried out while hiking.

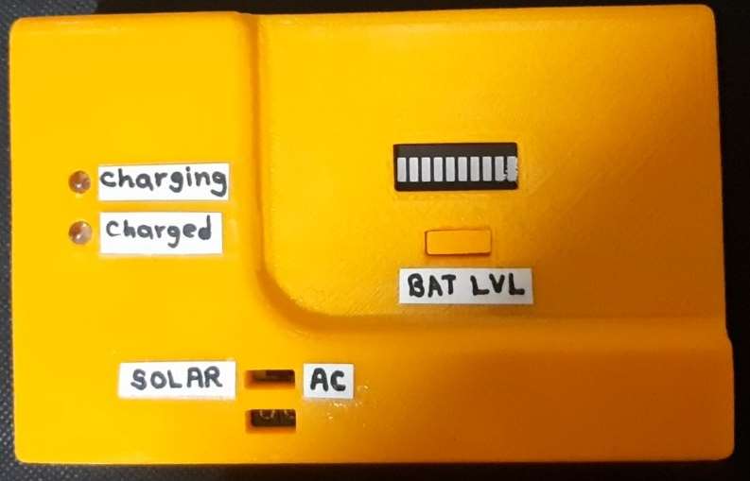
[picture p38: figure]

## 1.2. FUNCTIONALITY

Battery Charging Circuit, Mobile Charging Circuit, and Battery Status Indicator are the three main sections in our overall circuit. A user can charge up to two mobile phones at a time.

## Battery Charging

## Red LED is used to indicate whether the batteries are being charged and green LED is used to indicating once the batteries are charged. There are two modes in our Battery Charging

circuit. They are constant current mode and constant voltage mode.

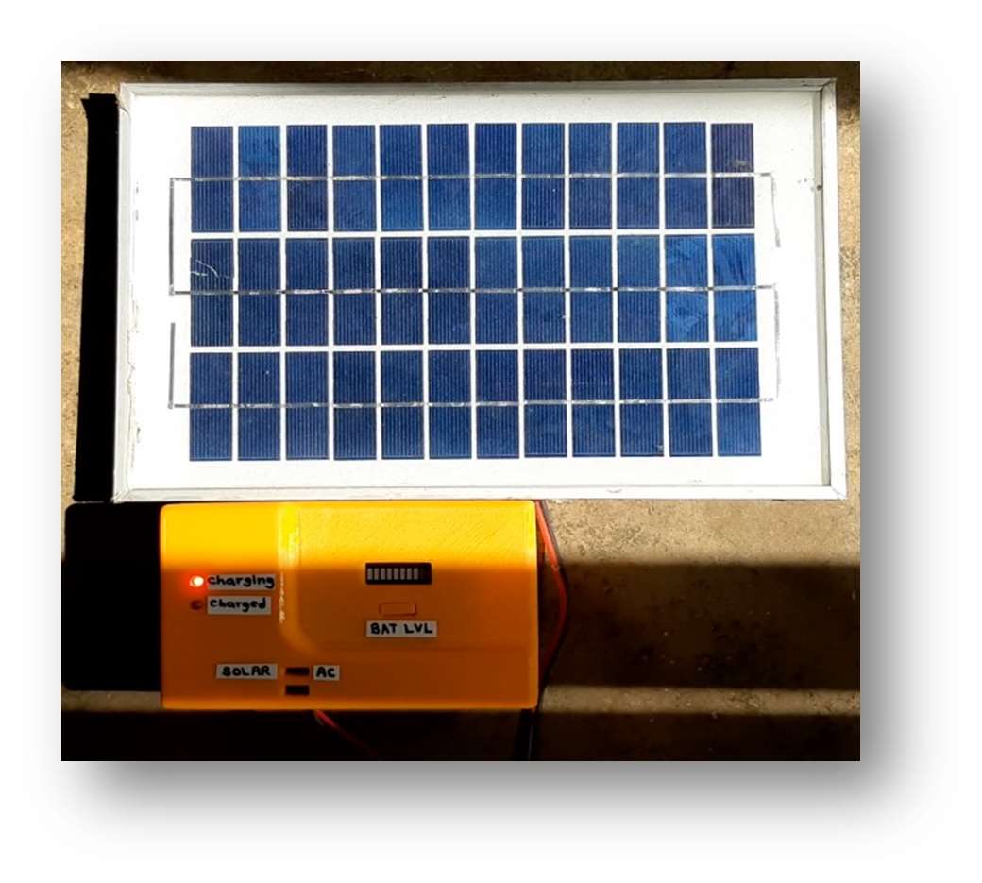
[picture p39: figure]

## Battery Level Indicator

For indicating battery levels, we have used four colors. Red indicates the battery level is

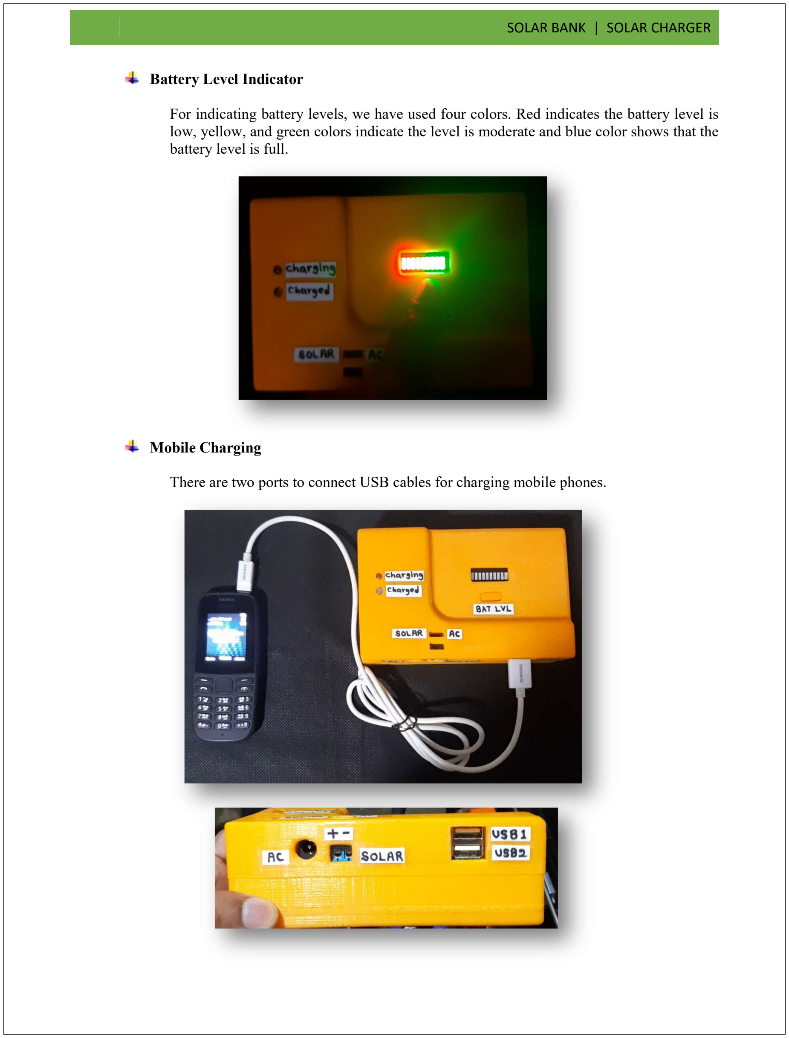
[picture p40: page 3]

low, yellow, and green colors indicate the level is moderate and blue color shows that the battery level is full.

## Mobile Charging

There are two ports to connect USB cables for charging mobile phones.

# 2. PRODUCTION PROCESS

## The following sections describe the PCB fabrication process, Soldering process, Enclosure

manufacturing process. Several parts are outsourced due to low volume of manufacturing and lack of locally available facilities.

## 2.1. PCB FABRICATION

The double-sided printed circuit board of the portable solar charger is outsourced to a Chinese PCB manufacturing company due to the lack of facilities locally. It is designed using Altium and then prototyped and tested manually before manufacturing. PCB layouts and the details of the manufacturer are given below.

## - JLCPCB – https://jlcpcb.com/

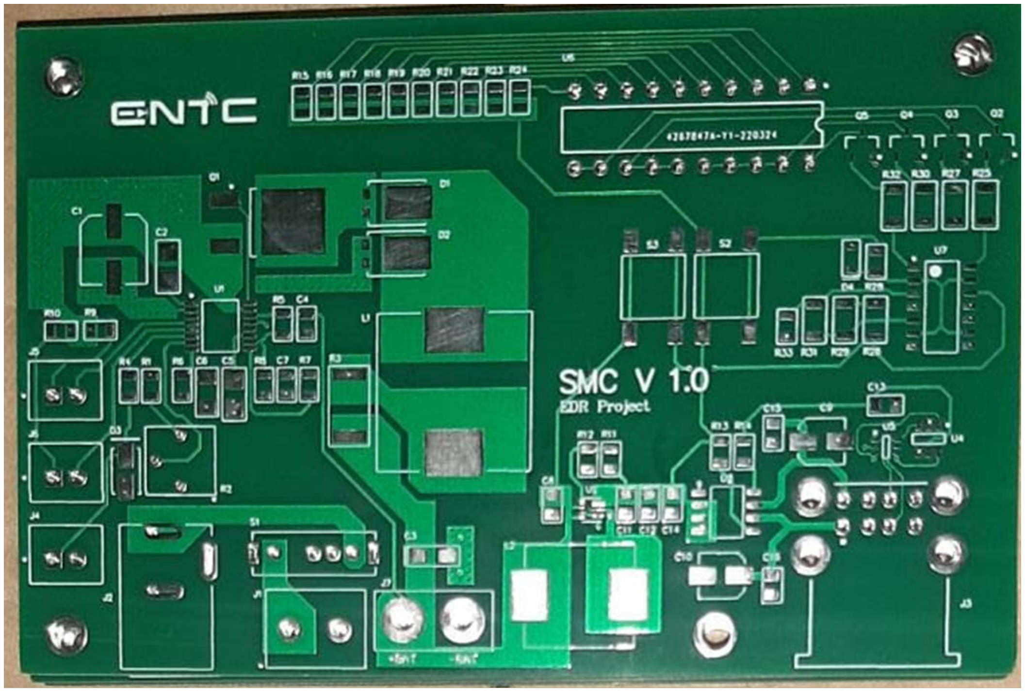
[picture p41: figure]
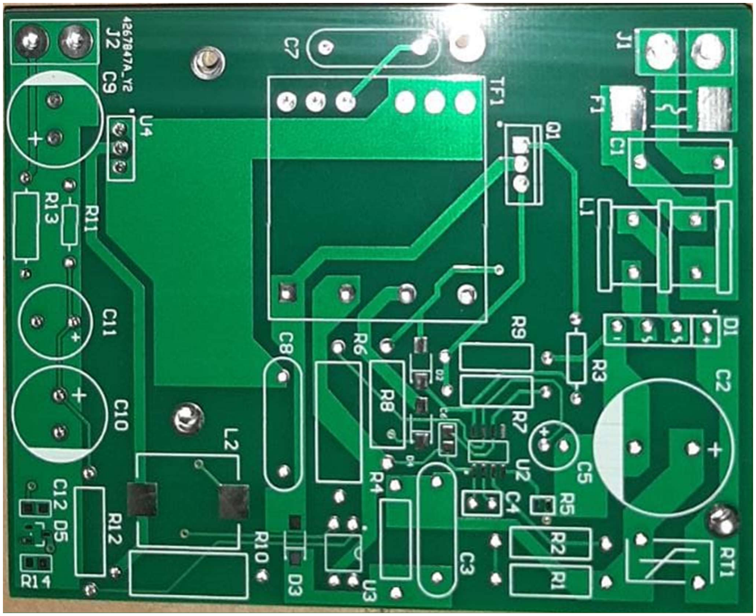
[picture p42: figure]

## 2.2. SOLDERING PROCESS

Due to the lower number of components per PCB and lower number of overall PCBs since this is

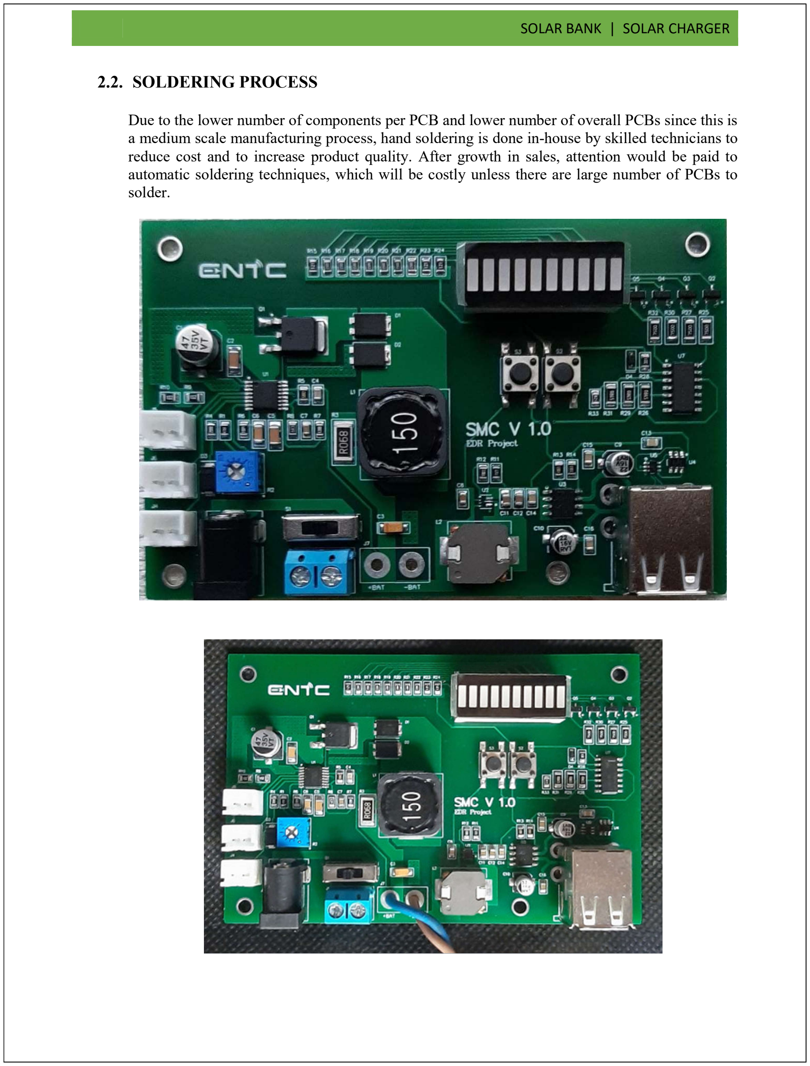
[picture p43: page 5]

a medium scale manufacturing process, hand soldering is done in-house by skilled technicians to reduce cost and to increase product quality. After growth in sales, attention would be paid to automatic soldering techniques, which will be costly unless there are large number of PCBs to solder.

## 2.3. ENCLOSURE MANUFACTURING PROCESS

The enclosure of Solar Bank consists of two main parts. The cover which contains PCB, ports, switches, LEDS and the base which contains battery holder. CAD software Solidworks 2021 is used to model the entire design. Although we have used 3D printing to manufacture the product, a proper analysis has been done in order to ensure that the design is fully moldable to use injection molding process for bulk production. PLA plastic is used to manufacture the product.

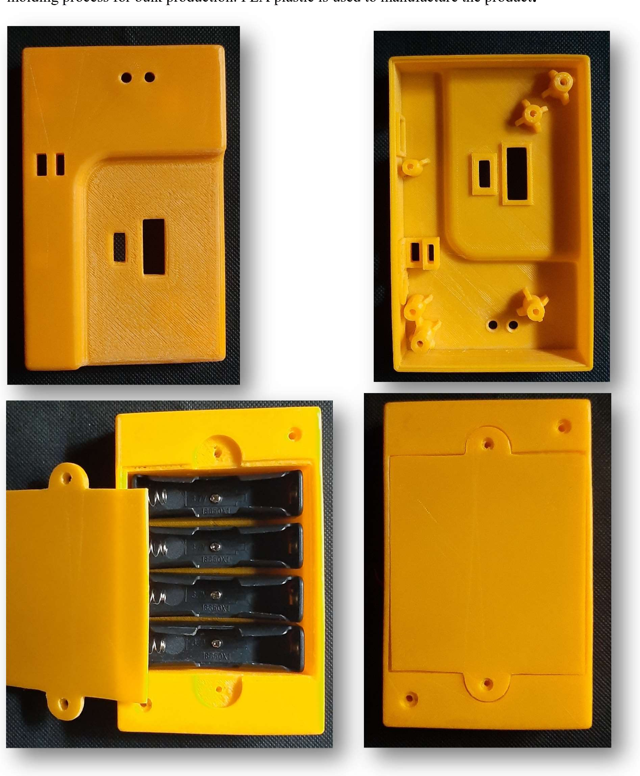
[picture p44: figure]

# 3. TESTING

Every PCB has been tested according to a proper and through testing processes that have to be executed before sending them to the market. The overall circuit has been divided into several sub circuits and then some inputs and desired test outputs have been used for testing. To ensure the enclosures are in high quality and are free of defects they have been passed through a quality control test that is done by members of quality control team.

# 4. ASSEMBLING

Items for assembling is selected after going through the testing and quality control procedures. Afterwards they have been assembled at the assembly division to produce the final product. The Bill of Materials and the list of suppliers of the components are provided in the Appendix.

# 5. PACKAGING

Device is packaged carefully inside a cardboard cubical box placed between a custom regiform fitting for shipping. Final package should include the following items;

## 1. Portable solar charger 2. Solar panel with cables 3. Power Cable 4. User Manual 5. Warranty certificate

# 6. APPENDIX

## 6.1. BILL OF MATERIALS

No | LCSC Electronics Part Number | Manufacturer Part Number | Description
1 | C90276 | VT1V470M0605 | 47uF 35V SMD Aluminum Electrolytic Capacitors
2 | C110253 | 1206B104K500NT | 100nF 50V SMD Multilayer Ceramic Capacitors
3 | C237220 | 1206B471K500CT | 470pF 50V SMD Multilayer Ceramic Capacitors
4 | C282753 | TCC0805X7R224K500DT | 220nF 50V SMD Multilayer Ceramic Capacitors
5 | C110055 | T491A106K016AT | 10uF 16V Tantalum Capacitors
6 | C2857996 | 0805CG110J500NT | 11pF 50V SMD Multilayer Ceramic Capacitors
7 | C100046 | RC0805JR-071KL | 1kΩ Chip Resistor - Surface Mount
8 | C70913 | MF11 103M | 10kΩ 450Mw Thermistors
9 | C81260 | 3362P-1-502LF | 5kΩ Plugin Variable Resistors/Potentiometers
10 | C114245 | RC0805FR-07120RL | 120Ω Chip Resistor - Surface Mount
11 | C445663 | ERA6AEB683V | 68kΩ Chip Resistor - Surface Mount ROHS
12 | C316211 | AR05BTCW5002 | 50kΩ Chip Resistor - Surface Mount
13 | C328397 | AECR0805F47K0K9 | 47kΩ Chip Resistor - Surface Mount
14 | C228604 | AC0805FR-071ML | 1MΩ Chip Resistor - Surface Mount
15 | C144578 | AC0805FR-07200RL | 200Ω Chip Resistor - Surface Mount
16 | C333703 | RTT25R068FTE | 0.068Ω Chip Resistor - Surface Mount
17 | C113945 | SB1045L | 45V 10A TO-277 Schottky Barrier Diodes
18 | C266552 | SS24 | 40V 2A DO-214AC Schottky Barrier Diodes
19 | C970540 | YPRH1508-150M | 8.5A 15uH ±20% 28mΩ SMD, Power Inductors
20 | C474881 | KF301-5.0-2P | 5mm Screw terminal
21 | C158012 | B2B-XH-A(LF)(SN) | 2.5mm Wire to Wire Connector
22 | C144401 | XHP-2 | 2.5mm Rectangular Connectors
23 | C77905 | CN3722 | TSSOP-16 Battery Management IC
24 | C296720 | CL21A226KOQNNNE | 22uF 16V SMD Multilayer Ceramic Capacitors
25 | C17816 | 0805W8F7323T5E | 732kΩ Chip Resistor - Surface Mount
26 | C915088 | TPS61022RWUR | VQFN-7 DC-DC Converters
27 | C17024 | CL21A106KPFNNNE | 10uF 10V SMD Multilayer Ceramic Capacitors
28 | C96346 | RC0805FR-07100KL | 100kΩ Chip Resistor - Surface Mount
29 | C2048948 | SPM10054T-1R0M-HZ | 27.5A 1uH ±20% 2.4mΩ - SMD Inductors
30 | C49678 | CC0805KRX7R9BB104 | 100nF 50V SMD Multilayer Ceramic Capacitors
31 | C44770 | TPS2513DBVR | SOT-23-6 Battery Management IC
32 | C217765 | ARG05FTC1003 | 100kΩ Chip Resistor - Surface Mount
33 | C130050 | TPS2066DR | SOIC-8_150mil Power Distribution Switches
34 | C72502 | RVT1C220M0405 | 22uF 16V SMD Aluminum Electrolytic Capacitors
35 | C2341 | 907-111A1012D10200 | USB 2.0 2 8 Female Type-A Plugin USB Connectors
36 | C194628 | TPD4E1U06DCKR | 6.5V Unidirectional SOT-363 ESD Protection Devices
37 | C127469 | SPEF220100 | 1A SMD Push Switches

38 | C173439 | BZT52C3V3S | 3.3V SOD-323 Zener Diodes
39 | C134081 | RC0805JR-07300RL | 300Ω Chip Resistor - Surface Mount
40 | C2933571 | FRC0805J821 TS | 820Ω Resistor - Surface Mount
41 | C243023 | MCWF12R59R0BTL | 59Ω Chip Resistor - Surface Mount
42 | C57473 | LM2902DR2G | 4 1MHz 3mA General Purpose SOIC-14_150mil Operational Amplifier
43 | C351454 | PTFR1206B750RP9 | 750Ω Chip Resistor - Surface Mount
44 | C18536 | 2N3904S-RTK/PS | 5mA NPN SOT-23 Bipolar Transistors
45 | C114244 | RC0805JR-07120RL | 120Ω Chip Resistor - Surface Mount
46 | C304819 | RS-05K1500FT | 150Ω Chip Resistor - Surface Mount
47 | C100045 | RC0805FR-070RL | 0Ω Chip Resistor - Surface Mount
48 | C2683746 | MBR30100CT | 100V 30A TO-220AB Schottky Barrier Diodes
49 | C2933374 | FRC0805F2321TS | 2.32kΩ Chip Resistor - Surface Mount
50 | C181890 | EL817(C)-F | 5000Vrms Transistor Optocouplers DIP-4 Optocouplers
51 | C111578 | TL431 | Adjustable SOT-23 Voltage References
52 | C20648 | KBP307 | 3A 600V KBP Bridge Rectifiers
53 | C433349 | CR6841S | SOP-8 AC-DC Controllers & Regulators
54 | C920725 | K104K275VC3L12 | 100nF 275V 10mm Suppression Capacitors
55 | C332361 | 5D-9 | 5Ω 3A NTC Thermistors
56 | C2841135 | HY2G820M180250CD288 | 400V 82uF Aluminum Electrolytic Capacitors
57 | C377841 | CC1H104ZA1FD3F6C1000 | 100nF 50V Ceramic Disc Capacitors
58 | C122218 | RI40-1W-820KΩ±2% T | 820kΩ Through Hole Resistors
59 | C122214 | RI40-1W-100KΩ±5% T | 100kΩ Through Hole Resistors
60 | C1380302 | FMP100FTF52-27R | 27Ω Through Hole Resistors
61 | C479229 | KNP1WS-100Ω±5%-XT52 | 100Ω Through Hole Resistors
62 | C176617 | MFR3WSJT-73-5R6 | 5.6Ω Through Hole Resistors
63 | C274866 | RFS01JR330A520NH | 330mΩ Through Hole Resistors
64 | C714113 | MF1W-10KΩ±1%T | 10kΩ Through Hole Resistors
65 | C601008 | M01W-1K±5%-TT63 | 1kΩ Through Hole Resistors
66 | C242154 | ERG2SJ751A | 750Ω Through Hole Resistors
67 | C385349 | RN1WS20KΩFT/BA1 | 20kΩ Through Hole Resistors
68 | C489107 | 35ZL1000MEFCG412.5X25 | 1000uF 35V Aluminum Electrolytic Capacitors
69 | C106604 | ERM1HM330E11OT | 33uF 50V Aluminum Electrolytic Capacitors
70 | C2896151 | DCH222Z30Y5VP6BL5A0 | 2.2nF 2kV Ceramic Disc Capacitors
71 | C779292 | MBR20200CT | 200V 10A TO-220AB Schottky Barrier Diodes
72 | C271452 | HF20N60 | 600V 20A 120W N Channel TO-220F MOSFET
73 | C2916149 | RS1M | 1A 1kV SMA Diodes – General Purpose
74 | C968816 | DCH472M30Y5VN6FJ5A0 | 4.7nF 1kV Ceramic Disc Capacitors
75 | C2907311 | FRC0805J243 TS | 24kΩ Chip Resistor - Surface Mount
76 | C116373 | UU9.8-5mH | 700mΩ 5mH @ 1kHz Through Hole Common Mode Filters
77 | C59354 | KF471M035G160A | 470uF 35V Aluminum Electrolytic Capacitors
78 | C1711 | CL21B104KBCNNNC | 100nF 50V SMD Multilayer Ceramic Capacitors

## 6.2. LIST OF SUPPLIERS

- SHENZHEN LCSC ELECTRONICS TECHNOLOGY CO., LTD.
79 | C351107 | YSPI1040-220M | 5A 22uH ±20% 73mΩ SMD Power Inductors
80 | C519909 | CC0805KRX7R7BB103 | 10nF 16V SMD Multilayer Ceramic Capacitors
81 | C381116 | DC-005-5A-2.0 | 5A 24V Plugin AC/DC Power Connectors
82 | C480348 | SS13D07L4B | 50V 0.3A Plugin Slide Switches
83 | C187586 | 046406.3DR | 100A SMD Fuse 6.3A 300mV SMD Fuses
84 | C879147 | AOD4185 | TO-252 MOSFETs
85 | C2938490 | JMTK440P04A | TO-252 MOSFETs
86 | C2839011 | 13007 | 10μA 400V 2W 9A TO-220 Bipolar Transistors

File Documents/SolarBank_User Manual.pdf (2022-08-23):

SOLAR BANK | SOLAR CHARGER

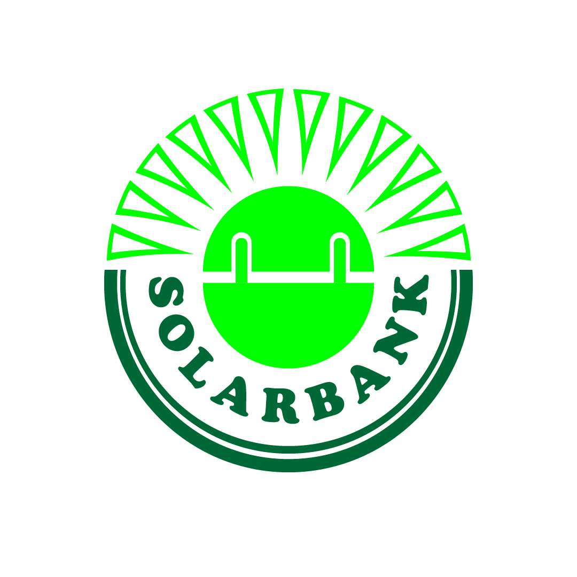
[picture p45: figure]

1 | P a g e

# USER MANUAL

2 | P a g e

## Table of Contents

3 | P a g e

## 1.)Introduction

Thank you for choosing the SolarBank stationary solar charger. This product will provide you an optimum solution to charge your mobile phone even with or without AC power supply staying wherever you are. As the product can be charged by AC power or solar, you can manually set the charging procedure. SolarBank charger has a battery of 10000mAh.
Please read the user manual completely before you begin operating the system.

### 1.1) Features

- Charging facility by both AC power and solar power
- 2 USB outputs
- Battery percentage indicator
- Charging indicator

### 1.2) Requirements

- 230V AC power or Solar power

### 1.3) Package Items

- Main Unit
- Power Adapter (optional)
- Solar panel
- Li-ion batteries
- User Manual
- Warranty Certificate

### 1.4) Specifications

Main Unit

Operational Voltage | Input: 7.5V to 28V Output: 5V
Rated Power | 40W
Material | Plastic
Size | 140mm x 89mm x 140mm
Weight | 500g

4 | P a g e

## 2.)Safety Precautions

When using this device always observe the enclosed safety instructions.
1. Make sure the main unit power supply adapter plug is completely pushed into the outlet. Failure to do so may cause electric shock and fire due to overheating
2. Do not attempt to repair or replace any part of this product unless specifically recommended in this user manual.
3. Do not use liquid or spray detergents to clean the device.
4. If anything abnormal such as a burning smell occurs, stop the operation immediately and unplug the device from the power source.
5. Always use the recommended power adapter.
6. Do not place heavy objects on the device.

## 3.) Getting to know the device

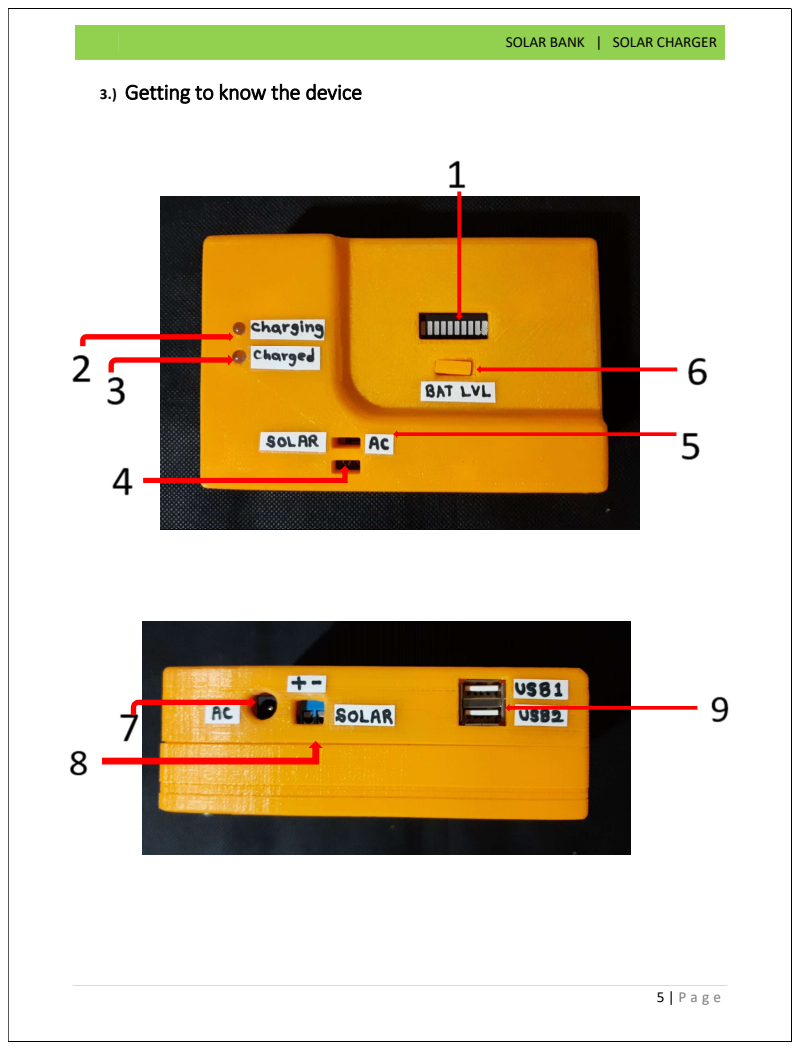
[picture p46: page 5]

6 | P a g e

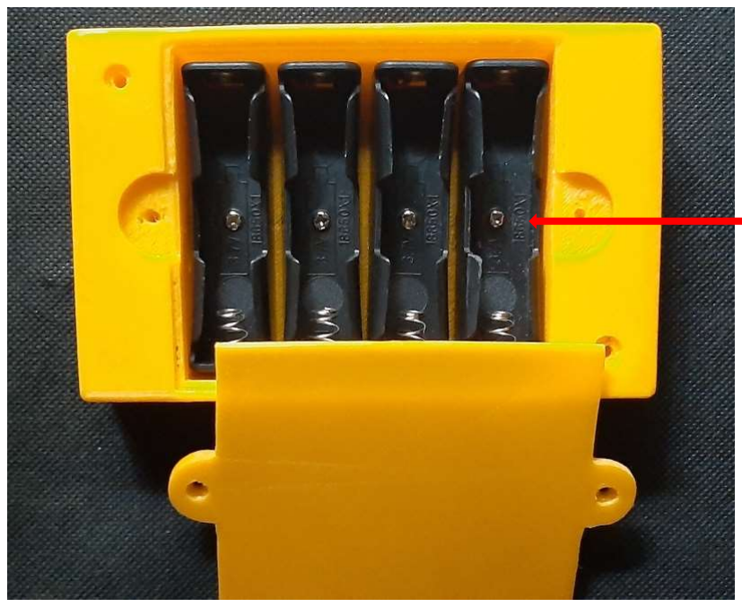
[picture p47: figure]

### 1 Battery Level Indicator 2 Charging indicator LED 3 Fully Charged indicator LED 4 Solar Panel Terminal 5 Switch 6 Batter Level Indicating Button 7 AC input 8 Solar Input Terminal 9 USB ports 10 Battery Holder

7 | P a g e

## 4.)Usage Instructions

1. Fix the batteries to the device.
2. Select your preferred powering method.
3. Connect the AC power or Solar panel as your above preference.
4. Charge the device until the battery percentage shows 100%.
5. Remove the powering method.
6. Connect your mobile phone through a USB cable to charge it.

## 5.)Troubleshooting

In case of any malfunction of the devices, try the following.
1. Make sure that the AC power adapter or solar panel is connected to the device correctly when charging the device.
2. Make sure that the power cord is plugged into a working electrical outlet.
3. Make sure that the switch works properly.
4. If those items are functioning properly contact authorized repairing personnel.

## 6.) Warranty Information

SolarBank warrants to the customer that this product will be free from defects in materials and workmanship under normal consumer usage for one (1) year from the date of original purchase. If SolarBank deems the claim to be warrantable, it will, at its sole option, repair, replace or refund the purchase price of the product. Product replacement will be with a functionally equivalent reconditioned / refurbished / pre-owned or new product, accessory or part. But the battery of the main unit will not be considered for this limited warranty.
This Limited One Year Warranty is a consumer’s exclusive remedy and is subject to the following exclusions:
| Altered Products: Any change, correction, abridged or illegible handwriting on the purchase tags or product instructions; Mismatched board serial numbers; Broken seals or that show evidence of tampering; Non-confirming or non-SolarBank housing, or components. Abuse and Misuse: Malfunction caused by damage, incorrect connection, or misusage; Undesirable phenomena due to contact with liquid, water, rain, extreme humidity or heavy perspiration, sand, dirt, or the like, extreme heat, or food.

8 | P a g e
- Normal Wear and Tear:
The product has been opened or disassembled; Periodic maintenance, repair, and replacement of parts due to normal wear and tear.
- Unauthorized Services or Modification:
Badness caused by service, testing, adjustment, installation, maintenance, alteration, modification in any way by someone other than SolarBank, or its authorized service centers.
- Communication Services:
Defects, damage, or the failure of products, accessories, or software due to any communication services or signal you may subscribe to or use with the products, accessories, or software.

For additional information: contact us on +94717979621

## 7.)Disposal

It is highly recommended not to dispose the product after its lifetime into the open environment. This product is made up of non-natural deteriorate materials like plastic, lead, copper, etc. Most of the materials used in making this product can be recovered, reused, and recycled. Make sure to property dispose the product according to your local environmental policies provided by the local government or local authority for information regarding the collection systems available. Packaging material are all recyclable (PE, LDPE, PP and cardboard).
Instructions
- If the product is non-functioning and still under the warranty period before throwing it away, please bring the product to us or contact us to make it functioning as before.
- If the product is non-functioning and the warranty period is over, you can bring it to any of our distribution outlets and receive a discount for the next Package you are buying.
- There are people who buy waste like plastic, e-waste etc. with the purpose of recycling them and safely. After taking the maximum use of the product, sell it to the people who are willing to buy them separately or the whole product together.
- Do not try to recycle on your own in unsafe conditions because this product contains potentially harmful materials like lead, cadmium, beryllium, etc. and recycling of e-waste may involve significant risk.
- Keep the product away from children specially when the product is not used anymore as they are sensitive to harmful e-waste.
- Recycling should be done according to the rules and regulations of the government.
- Please dispose the used over product according to the given instructions as responsible citizens because informal and processing of e-waste may cause adverse human and animal health effects.

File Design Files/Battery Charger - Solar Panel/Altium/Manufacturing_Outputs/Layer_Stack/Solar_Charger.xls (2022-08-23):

Board Stack Report
Stack Up |  | Layer Stack
Layer | Board Layer Stack | Name | Material | Thickness | Constant
1 |  | Top Paste
2 |  | Top Overlay
3 |  | Top Solder | Solder Resist | 0.025mm | 3.5
4 |  | Top Layer | Copper | 0.070mm
5 |  | Dielectric 1 | FR-4 | 1.000mm | 4.8
6 |  | Bottom Layer | Copper | 0.070mm
7 |  | Bottom Solder | Solder Resist | 0.025mm | 3.5
8 |  | Bottom Overlay
9 |  | Bottom Paste
 | Height : 1.190mm

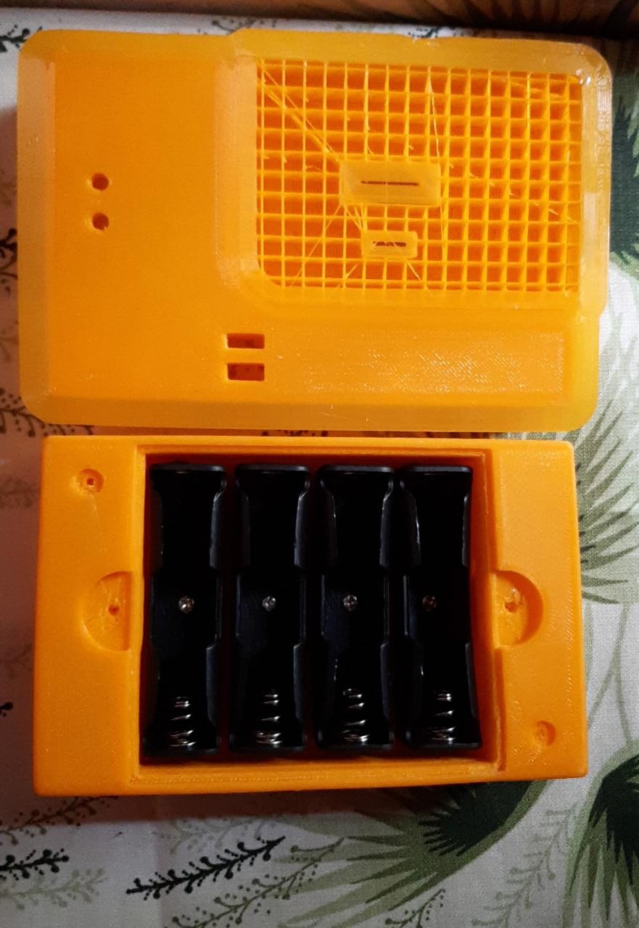
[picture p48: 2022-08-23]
Images/PrintedEnclosureBack.jpeg

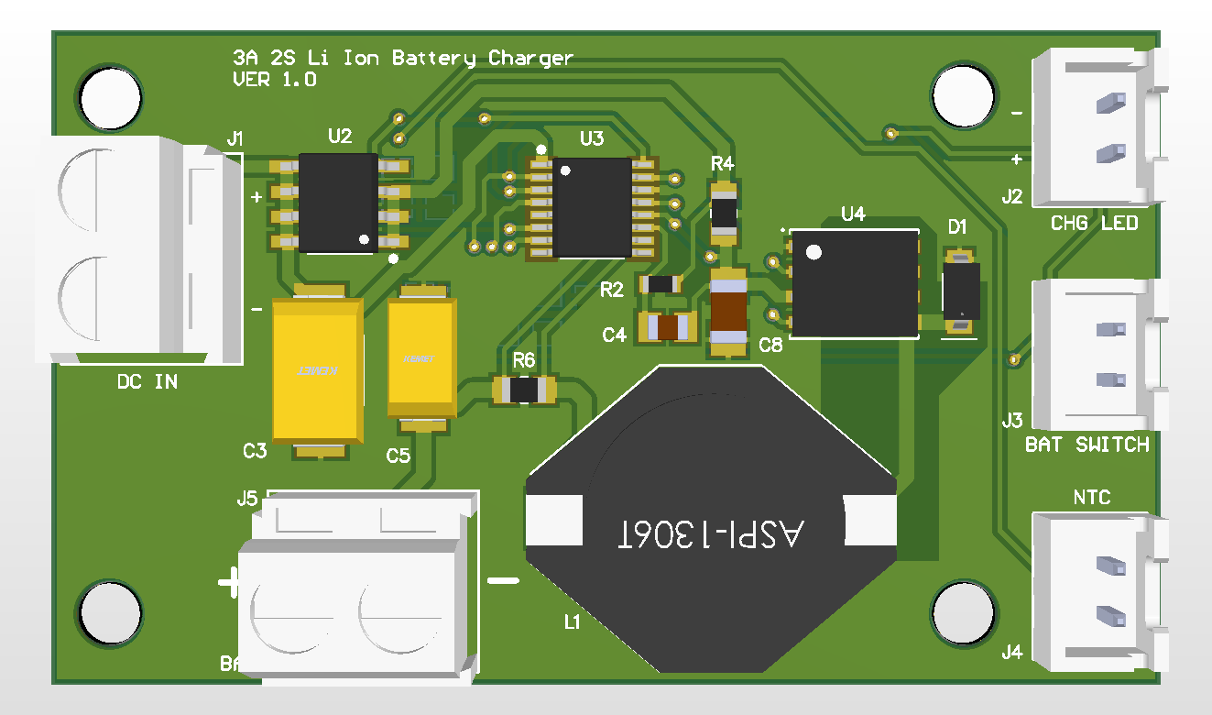
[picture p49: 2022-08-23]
Design Files/Battery Charger - Solar Panel/Altium/Manufacturing_Outputs/3D View/Solar_Charger_Top.png

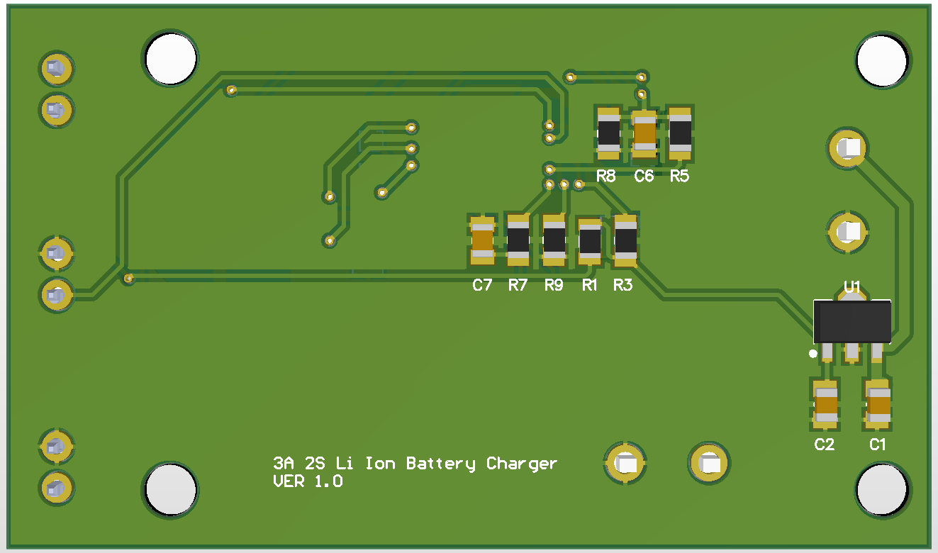
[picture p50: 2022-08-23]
Design Files/Battery Charger - Solar Panel/Altium/Manufacturing_Outputs/3D View/Solar_Charger_Bottom.png

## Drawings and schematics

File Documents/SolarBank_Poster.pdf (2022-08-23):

# SOLAR CHARGER

USB power | Solar charging | renewable energy

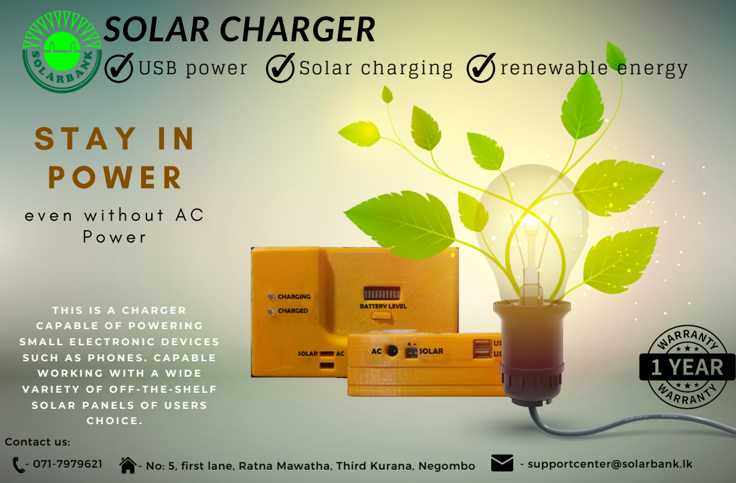
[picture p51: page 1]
Contact us:; - No: 5, first lane, Ratna Mawatha, Third Kurana, Negombo; - supportcenter@solarbank.lk

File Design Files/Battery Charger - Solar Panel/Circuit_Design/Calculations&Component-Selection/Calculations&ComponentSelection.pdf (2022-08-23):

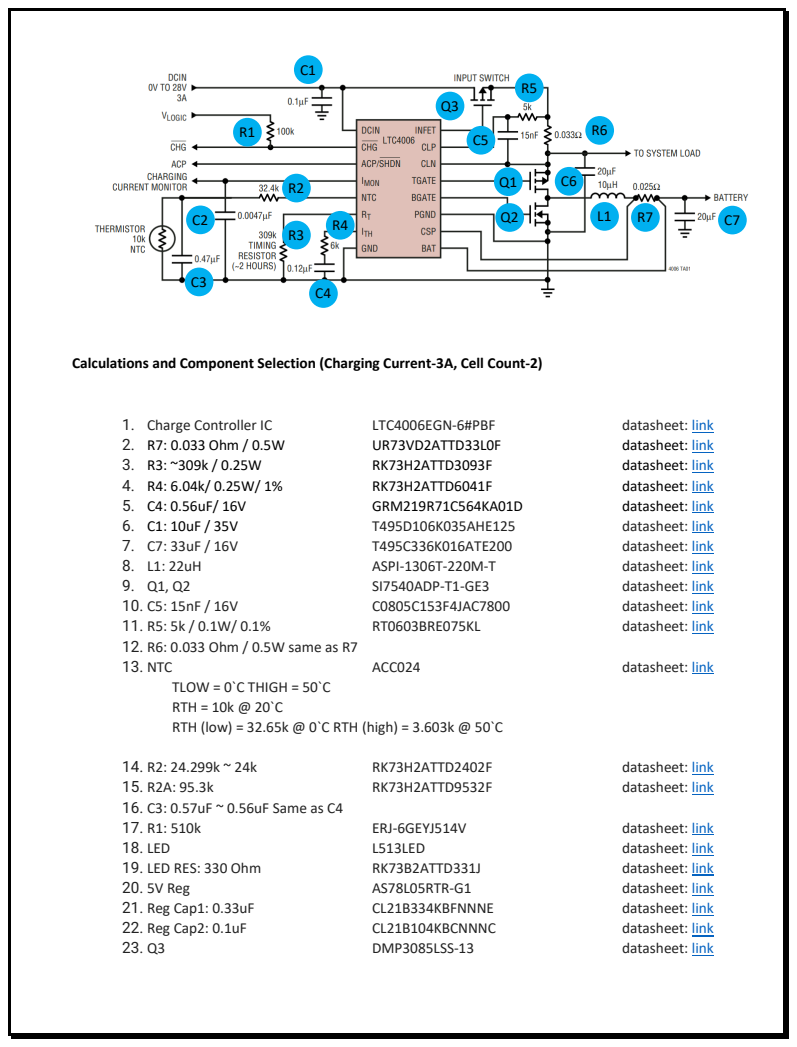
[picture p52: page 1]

Calculations and Component Selection (Charging Current-3A, Cell Count-2)

TLOW = 0`C THIGH = 50`C
RTH = 10k @ 20`C
RTH (low) = 32.65k @ 0`C RTH (high) = 3.603k @ 50`C

24. D1 | MBR130T1G | datasheet: link (https://www.onsemi.com/pdf/datasheet/mbr130t1-d.pdf)
25. C6: 20uF / 50V | C3216X5R1V226M160AC | datasheet: link (https://product.tdk.com/system/files/dam/doc/product/capacitor/ceramic/mlcc/catalog/mlcc_commercial_general_en.pdf)
26. NTC Connector, ACP Connector | B2B-XH-A(LF)(SN) | datasheet: link (https://www.jst-mfg.com/product/pdf/eng/eXH.pdf)
27. DC INPUT Connector | 282834-2 | datasheet: link (https://www.te.com/commerce/DocumentDelivery/DDEController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)

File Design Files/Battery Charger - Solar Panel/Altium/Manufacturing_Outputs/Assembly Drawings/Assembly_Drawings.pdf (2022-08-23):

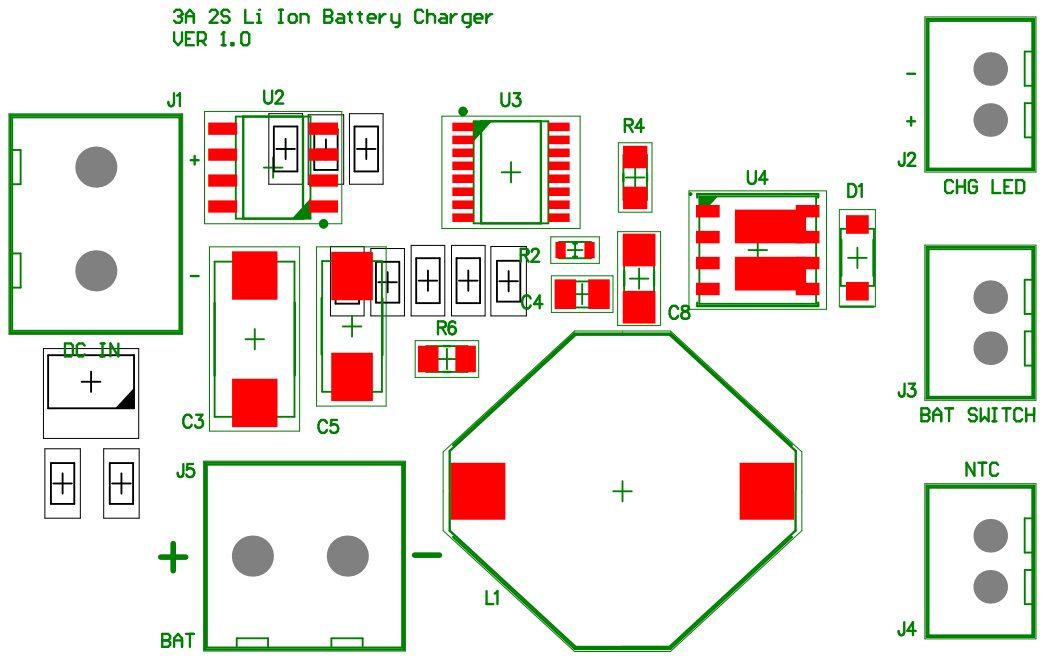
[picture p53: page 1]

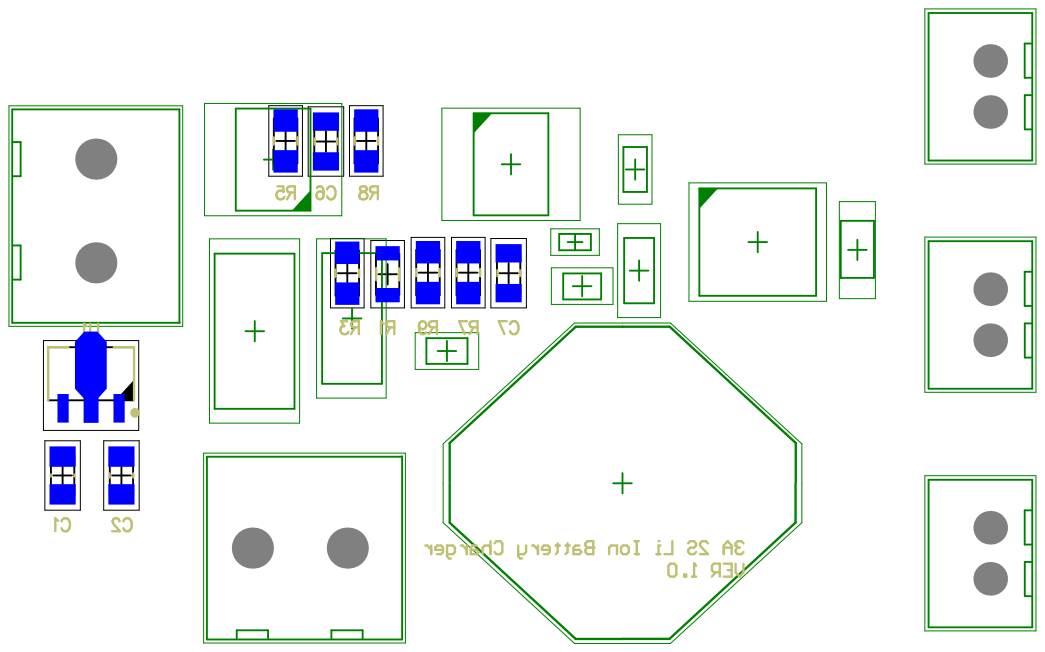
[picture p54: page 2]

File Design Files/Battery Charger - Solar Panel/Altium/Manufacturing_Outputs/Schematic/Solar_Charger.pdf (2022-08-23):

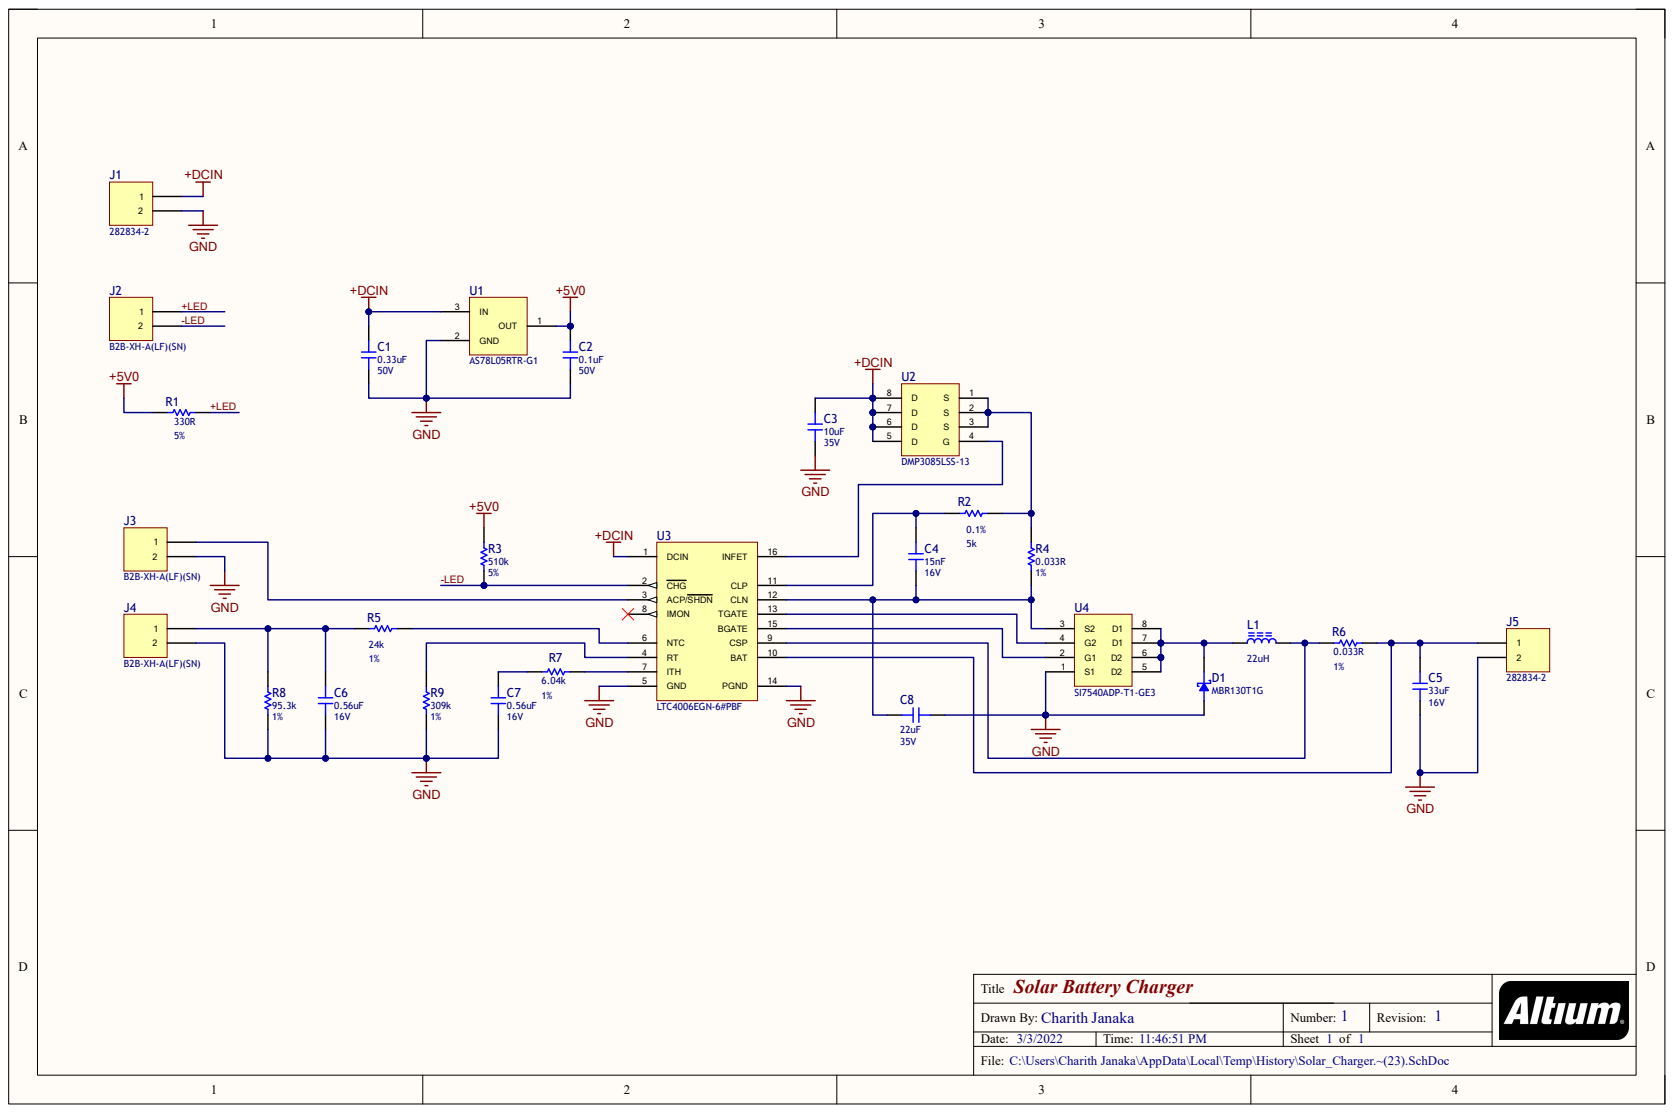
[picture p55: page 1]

Charith Janaka
C:\Users\Charith Janaka\AppData\Local\Temp\History\Solar_Charger.~(23).SchDoc

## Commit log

2022-08-23 files added
    [18650 Battery Holder 4x-18650 Battery Holder 4x.STEP1.SLDPRT, 18650 battery holder.SLDPRT, 18650 battery holder.STEP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]
2022-08-24 solar charger image added
